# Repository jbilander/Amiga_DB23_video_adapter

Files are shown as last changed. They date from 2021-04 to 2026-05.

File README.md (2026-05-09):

# Amiga DB23 Video Adapter

## Overview

The Amiga DB23 Video Adapter is a small plug-mounted PCB that fits directly onto the Amiga's 
DB23 video port. It is primarily used to build Amiga video cables — either a SCART (RGBS) or 
VGA (RGBHV) cable — while also buffering and filtering the Amiga's analog video signals for 
use with modern displays. Optionally, it allows switching between true PAL and NTSC clock 
frequencies without rebooting or using software.

***

<a href="images/Amiga_DB23_video_adapter_rev1b_pic15.jpg">
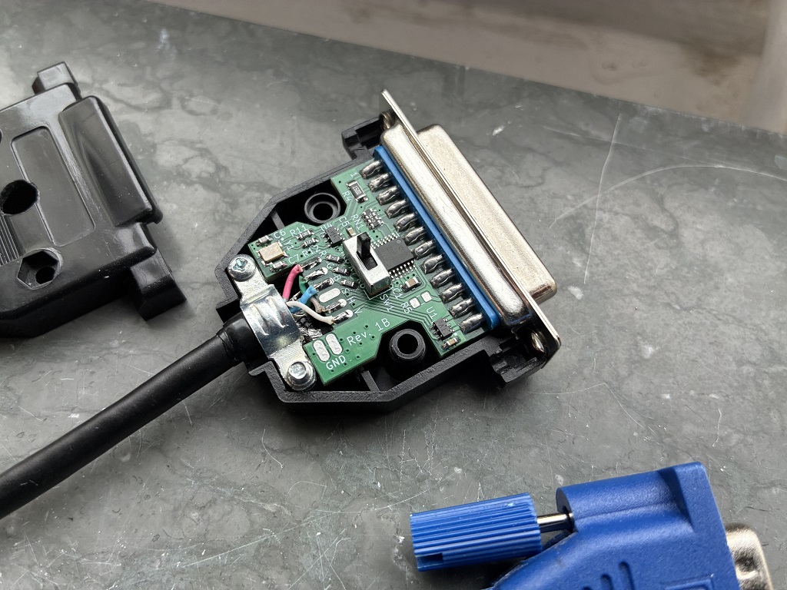
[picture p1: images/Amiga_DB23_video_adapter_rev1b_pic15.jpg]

</a>
<a href="images/Amiga_DB23_video_adapter_rev1b_pic16.jpg">
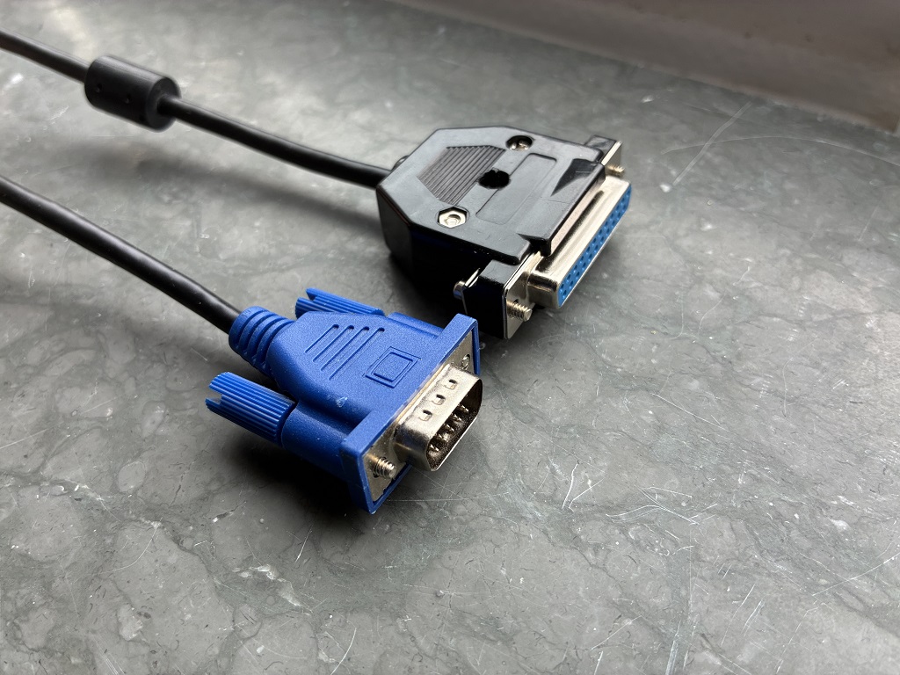
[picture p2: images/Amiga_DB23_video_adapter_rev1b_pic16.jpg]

</a>

***

<a href="images/Amiga_DB23_video_adapter_rev1b_pic1.png">
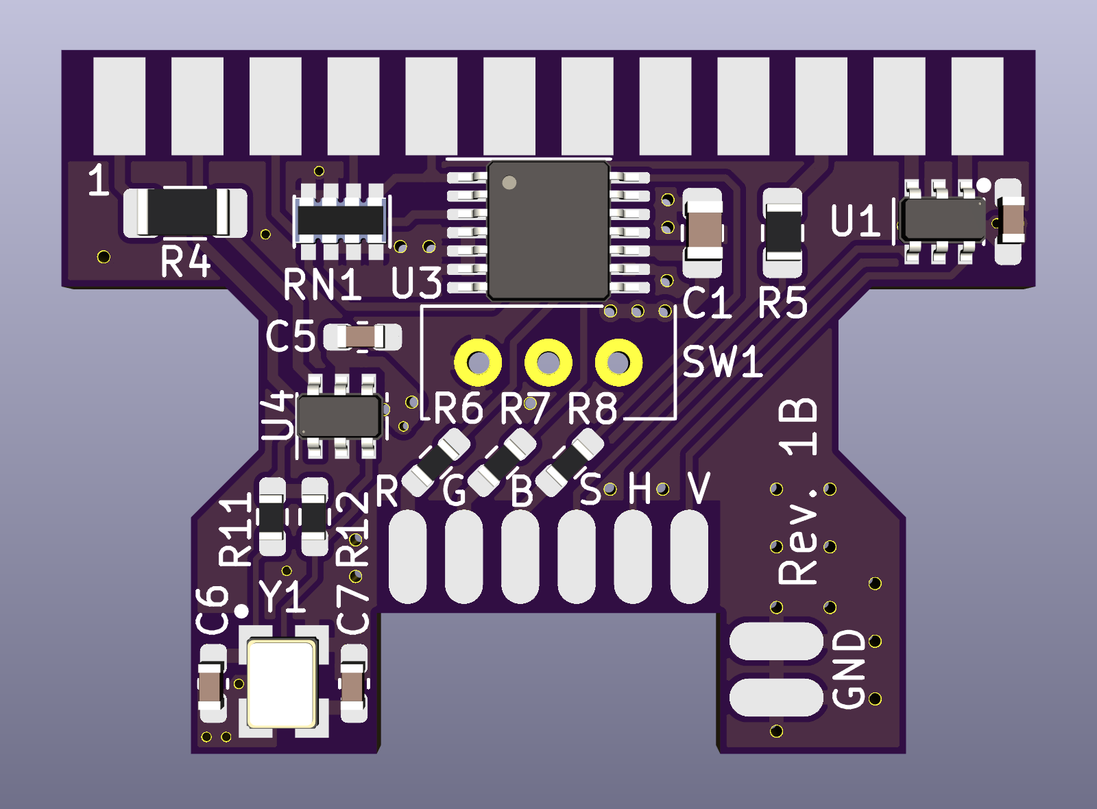
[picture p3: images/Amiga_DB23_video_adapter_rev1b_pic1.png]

</a>
<a href="images/Amiga_DB23_video_adapter_rev1b_pic2.png">
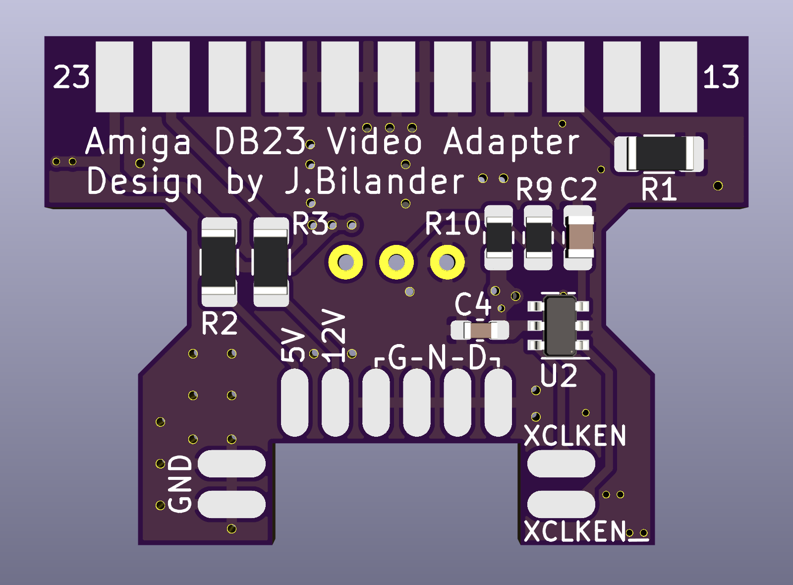
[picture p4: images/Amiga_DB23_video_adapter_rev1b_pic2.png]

</a>
<br />
<a href="images/Amiga_DB23_video_adapter_rev1b_pic3.png">
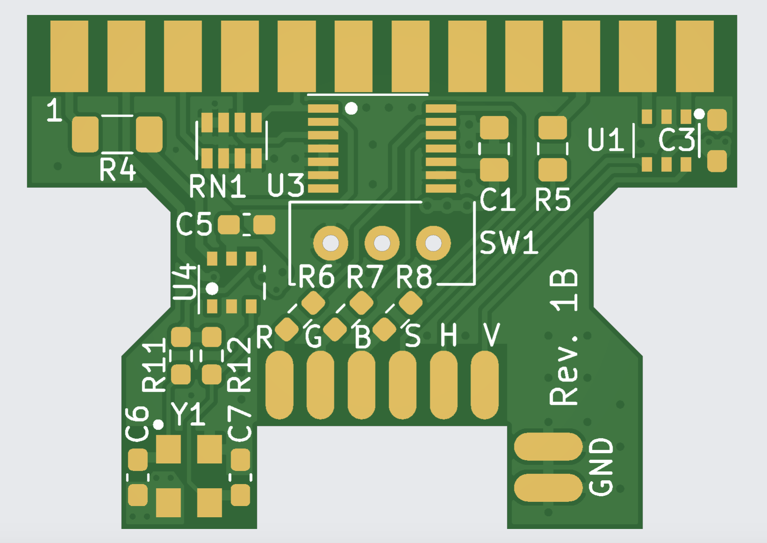
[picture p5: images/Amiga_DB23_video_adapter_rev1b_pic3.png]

</a>
<a href="images/Amiga_DB23_video_adapter_rev1b_pic4.png">
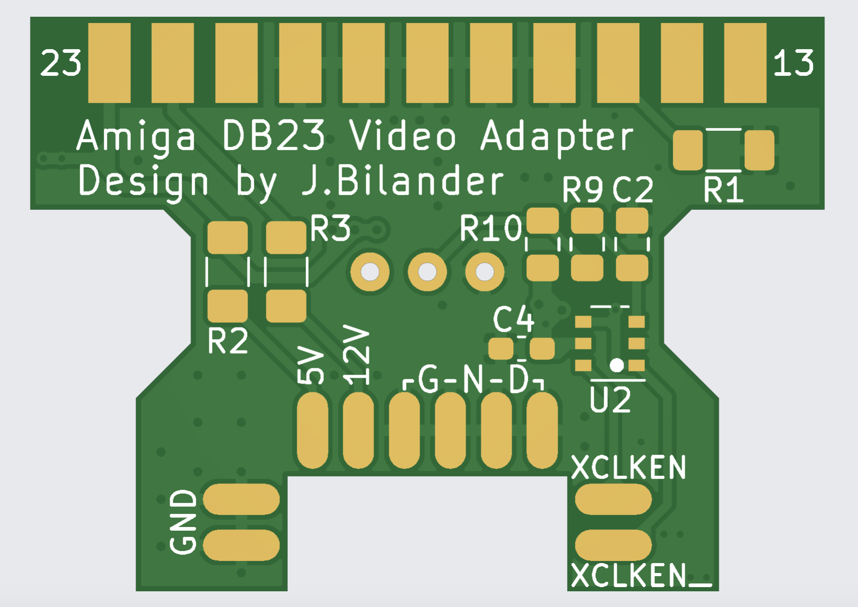
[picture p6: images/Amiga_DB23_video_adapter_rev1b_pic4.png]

</a>

***

### Video Signal Conditioning (Rev 1B)

- **HSync and VSync** are passed through a dual non-inverting Schmitt-trigger buffer (U1) to 
  reduce jitter and noise on the sync lines.
- **RGB signals** are routed through a THS7374 4-channel video amplifier (U3) with its 
  low-pass filter enabled. This effectively removes the horizontal banding and "jailbar" 
  interference patterns commonly seen when connecting an Amiga's 15 kHz signal to LCD displays.
  > ⚠️ A 15 kHz-capable display is required. See [15khz.wikidot.com](http://15khz.wikidot.com/) 
  > for compatible monitors.

### PAL/NTSC Clock Switching (Optional)

When a crystal oscillator (Y1) is populated, the adapter can supply an external pixel clock 
to the Amiga's Agnus/Alice chip, allowing the machine to be switched between PAL and NTSC 
video modes. The slide switch (SW1) enables or disables the `/XCLKEN` signal — when asserted, 
this tells Agnus/Alice to use the external clock from the adapter instead of the onboard 
motherboard oscillator.

The switch itself is hardware-debounced using a resistor-capacitor (RC) circuit combined with 
the hysteresis of a dual-inverting Schmitt-trigger IC (U2), ensuring clean, glitch-free 
switching.

Two solder pads (`XCLKEN` and `/XCLKEN`) are provided on the PCB. An optional jumper wire 
can be soldered from one of these pads back to pin 41 of a switchable Agnus chip 
(or JP4 on the A500 Rev. 6A board), so that the switch on the adapter controls both the 
external clock enable and the Agnus clock selection simultaneously.

> ⚠️ **Before attempting this mod**, verify that your Agnus revision supports hardware 
> PAL/NTSC switching, and confirm that JP4 is not already bridged to GND. 
> All ECS Agnus chips can be switched in **software** if the hardware pin is not available — 
> use the Early Startup Menu (hold both mouse buttons at reset) on KS 3.0+, or a tool 
> such as [Degrader](https://aminet.net/package/util/boot/Degrader).

#### Choosing the correct crystal and solder pad

Install a crystal **opposite** to the one already on your Amiga's motherboard:

| Motherboard oscillator | Install crystal | Solder jumper wire to pad |
|---|---|---|
| PAL (28.37516 MHz) | NTSC (28.63636 MHz) | `XCLKEN` |
| NTSC (28.63636 MHz) | PAL (28.37516 MHz)  | `/XCLKEN` |

> The jumper wire is entirely optional. Without it you can still enable/disable the external 
> clock via SW1, and switch the Agnus video mode independently through software or the 
> Early Startup Menu.

---

## Why use this adapter with XCLK?

You don't have to — but being able to switch between true native PAL and true native NTSC on 
the same machine is a very compelling feature. It gives you:

- ✅ Correct **aspect ratio** for game graphics designed for a specific video standard
- ✅ Correct **sound playback speed** (PAL/NTSC run at different clock rates)
- ✅ Correct **gameplay speed** and smooth scrolling in both PAL 50 Hz and NTSC 60 Hz

For example, compare the screenshots below from *Defender of the Crown*, with its stunning 
artwork by artist **Jim Sachs**. The game was designed for NTSC and looks significantly better 
in NTSC mode (bottom row) — in PAL mode (top row) everything appears vertically squashed.

<br />

**PAL (top) vs NTSC (bottom):**

<a href="images/pal_vs_ntsc_pic1.jpg">
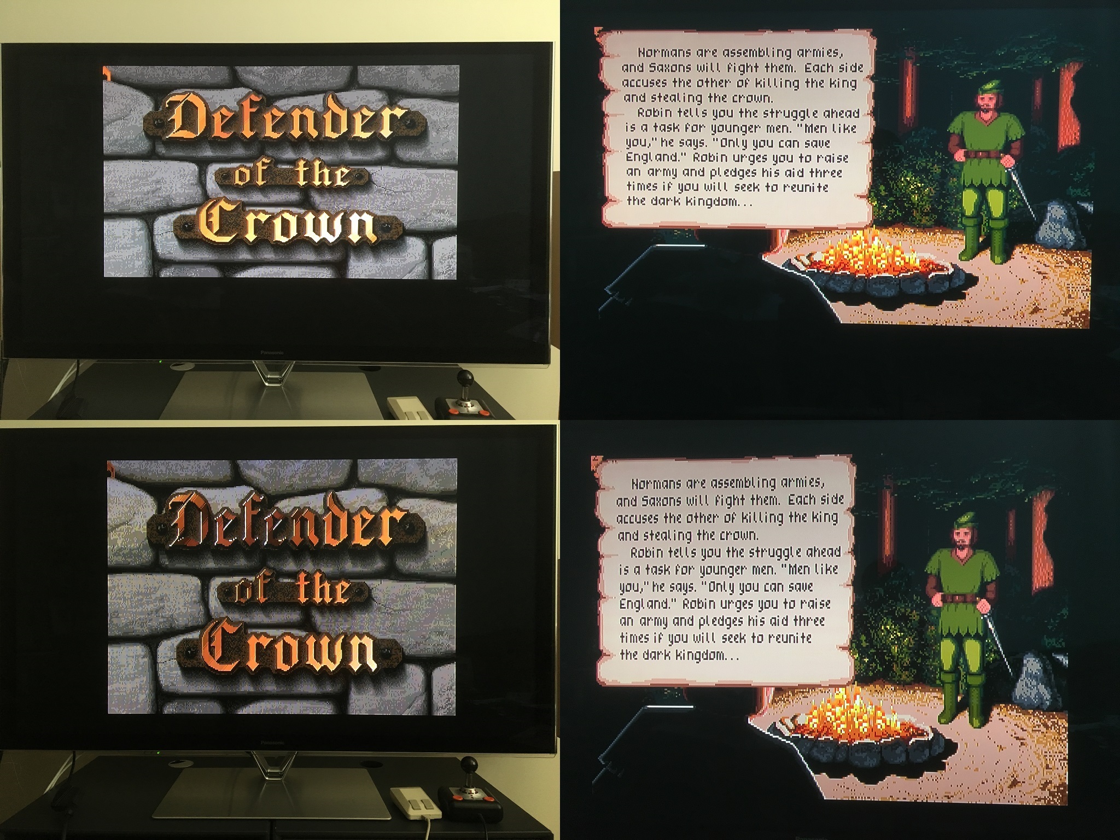
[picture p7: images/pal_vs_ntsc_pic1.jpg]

</a>
<a href="images/pal_vs_ntsc_pic2.jpg">
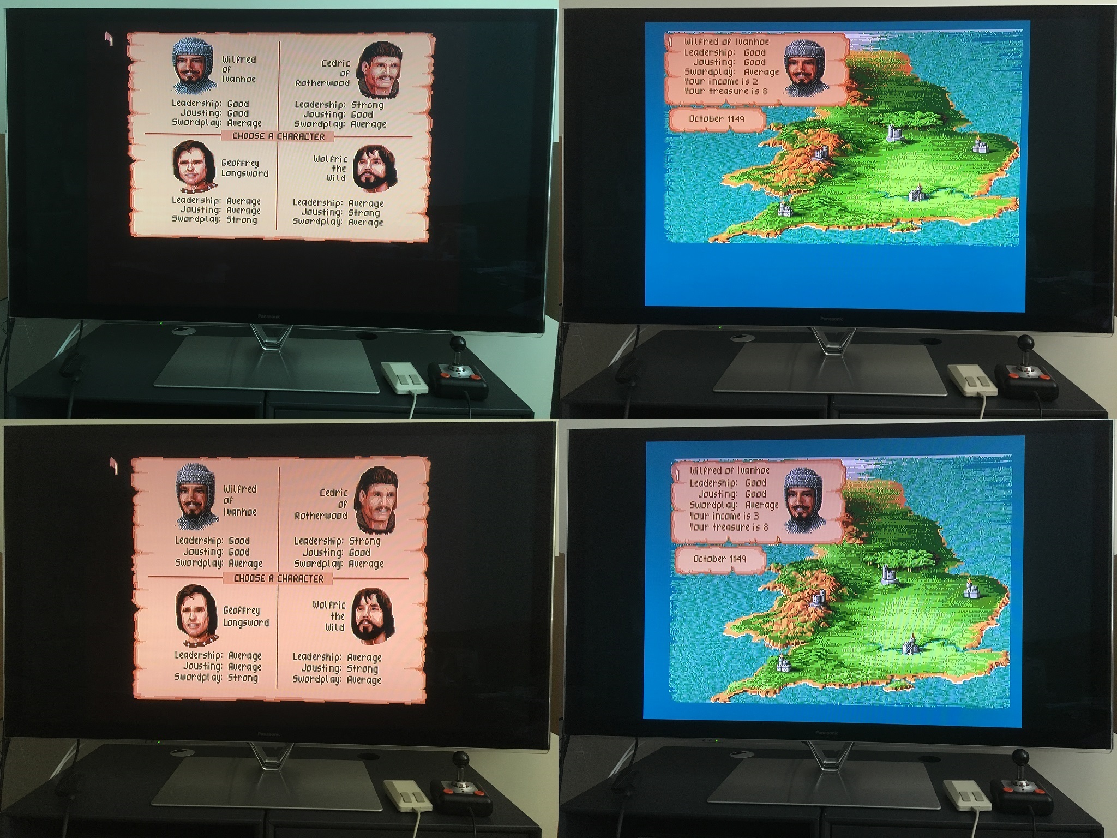
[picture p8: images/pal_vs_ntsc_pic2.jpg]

</a>

***

## Usage Scenarios

### 1 — Amiga DB23 to SCART (RGBS)
Build a cable carrying RGB + Composite Sync (CSync) to a SCART-equipped display.  
U1 and C3 are **not required** in this configuration.  
Y1 can optionally be populated for PAL/NTSC switching as described above.

### 2 — Amiga DB23 to VGA (RGBHV)
Build a cable carrying RGB + separate HSync/VSync to a VGA monitor.  
Requires a [15 kHz-compatible monitor](http://15khz.wikidot.com/).  
U1 and C3 **are required** in this configuration.  
Y1 can optionally be populated for PAL/NTSC switching as described above.

### 3 — Plug only, no cable (clock switching only)
Populate Y1 and the XCLK circuitry, but attach no output cable. Useful if you are already 
using an RGBtoHDMI or similar device for display output but want to retain hardware 
PAL/NTSC switching via the adapter's switch.

***

## Bill of Materials (Rev 1B and 1C)

**J1, U3 and RN1 are required for both SCART and VGA builds.**

| Reference | Qty | Value | Description | Package | Mouser / Notes |
|---|-----|---|---|---|---|
| J1 | 1 | DB23 Female | DB-23 female connector (Amiga video port) | DB-23 | [Aliexpress DB23 Female](https://www.aliexpress.com/item/1005004634222021.html) |
| U1 | 1 | 74HCT2G17 | Dual non-inverting Schmitt-trigger buffer — **VGA only** | TSOP-6 | [771-HCT2G17GV125](https://www.mouser.com/ProductDetail/771-HCT2G17GV125) |
| U2 | 1 | 74HCT2G14 | Dual inverting Schmitt-trigger buffer (SW1 debounce) — **XCLK optional** | TSOP-6 | [771-HCT2G14GV125](https://www.mouser.com/ProductDetail/771-HCT2G14GV125) |
| U3 | 1 | THS7374IPWR | 4-channel video amplifier with low-pass filter | TSSOP-14 | [595-THS7374IPWR](https://www.mouser.com/ProductDetail/595-THS7374IPWR) |
| U4 | 1 | 74LVC1GX04 | Crystal clock buffer — **XCLK optional** | TSOP-6 | [771-LVC1GX04GV125](https://www.mouser.com/ProductDetail/771-LVC1GX04GV125) |
| Y1 | 1 | 28.37516 MHz (PAL) or 28.63636 MHz (NTSC) | Crystal oscillator, CL=16pF — **XCLK optional** | 3.2 x 2.5 mm | e.g. ABM8-28.375MHZ-B2-T (PAL) or ECS-286.3-18-33-JEM-TR (NTSC) |
| RN1 | 1 | 75Ω | Resistor network, 4× 75Ω isolated (CAT16-75R0F4LF) | 1206 | [CAT16-75R0F4LF](https://www.mouser.com/ProductDetail/652-CAT16-75R0F4LF) |
| SW1 | 1 | SW_SPDT | Slide switch, enables/disables `/XCLKEN` (external clock to Agnus/Alice). Recommended: SS12D00 3-pin 1P2T, pin pitch 2.5 mm, handle length 5 mm — **XCLK optional** | | e.g. [AliExpress SS12D00](https://www.aliexpress.com/item/1005008330569768.html) |
| R1 | 1 | 100Ω | **Optional** — CCK clock termination. Populate only if experiencing clock interference noise. See [vidmod fix](http://www.l8r.net/technical/wblock/a4000hard/vidmod.html) | 1206 | |
| R2 | 1 | 75Ω | RGB mode autoselect — **SCART only** (drives SCART pin 16 high for RGB mode) | 1206 | |
| R3 | 1 | 1kΩ | AV mode autoselect — **SCART only** (drives SCART pin 8 high at 9.5–12V so TV automatically switches to SCART input) | 1206 | |
| R4 | 1 | 150Ω | Damping resistor XCLK-line — **XCLK optional** | 1206 | |
| R5 | 1 | 330Ω | CSync resistor — **SCART only** | 0805 | |
| R6, R7, R8 | 3 | 75Ω | Video termination resistor | 0603 | |
| R9, R10 | 2 | 10kΩ | Resistor (SW1 RC debounce) — **XCLK optional** | 0805 | |
| R11 | 1 | 1kΩ | Resistor — **XCLK optional** | 0603 | |
| R12 | 1 | 2.2MΩ | Resistor — **XCLK optional** | 0603 | |
| C1, C2 | 2 | 100nF | Decoupling capacitor | 0805 | (C2 is for SW1 RC debounce)|
| C3 | 1 | 100nF | Decoupling capacitor — **VGA only** | 0603 | |
| C4, C5 | 2 | 100nF | Decoupling capacitor — **XCLK optional** | 0603 | |
| C6, C7 | 2 | 32pF | Crystal load capacitor (06031A320FAT2A) — **XCLK optional** | 0603 | [581-06031A320FAT2A](https://www.mouser.com/ProductDetail/581-06031A320FAT2A) |

### Partial BOM by build type

| Component | Mandatory (both) | SCART only | VGA only | XCLK optional |
|---|:---:|:---:|:---:|:---:|
| J1, U3, RN1 | ✅ | | | |
| C1, R6, R7, R8 | ✅ | | | |
| R2, R3, R5 | | ✅ | | |
| U1, C3 | | | ✅ | |
| U2, U4, Y1, SW1 | | | | ✅ |
| C2, C4, C5, C6, C7 | | | | ✅ |
| R4, R9, R10, R11, R12 | | | | ✅ |
| R1 | optional | | | |

### SCART cable wiring reference

| Signal | Resistor | Value | SCART pin | Notes |
|---|---|---|---|---|
| CSync  | R5 | 330Ω | Pin 20 | Composite sync / composite video in, 1V incl. sync |
| +5V | R2 | 75Ω  | Pin 16 | RGB select: High (1–3V) = RGB mode, Low (0–0.4V) = Composite |
| +12V | R3 | 1kΩ  | Pin 8  | AV autoswitch: High (9.5–12V) = AV mode, Low (0–2V) = TV mode |

### VGA cable reference

U1 (74HCT2G17) buffers HSync and VSync. Datasheet: [74HC/HCT2G17](https://assets.nexperia.com/documents/data-sheet/74HC_HCT2G17.pdf)

---

## How to build Rev 1B

The following step-by-step guide documents a VGA (RGBHV) cable build using a cheap 
thin VGA cable as the source, which works very well since these cables already contain 
individually shielded wires inside.

### Step 1 — Prepare the DB23 connector

<a href="images/Amiga_DB23_video_adapter_rev1b_pic5.jpg">
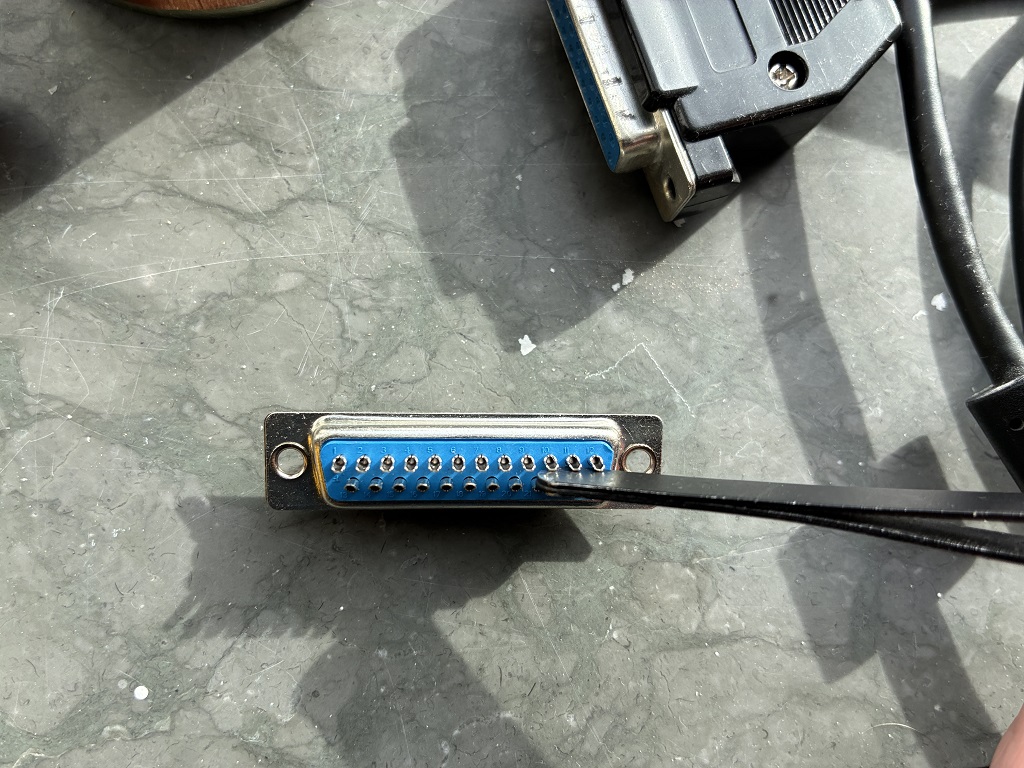
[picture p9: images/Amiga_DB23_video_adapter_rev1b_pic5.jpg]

</a>

Start by gently prying the solder lug pins outward slightly on the DB23 connector so 
that they can wrap around the standard 1.6 mm PCB thickness. The back of a pair of 
tweezers works well for this — just enough to open them up without bending them too far.

### Step 2 — Fit the PCB into the connector

<a href="images/Amiga_DB23_video_adapter_rev1b_pic6.jpg">
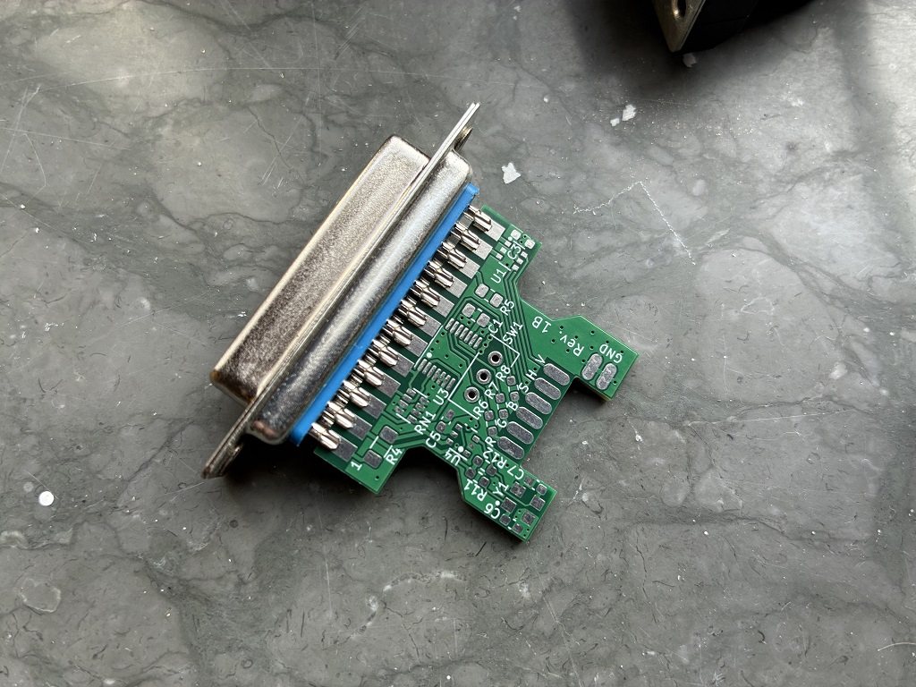
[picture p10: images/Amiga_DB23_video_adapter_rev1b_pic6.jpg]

</a>

Carefully sandwich the PCB between the solder cups of the connector, making sure the 
alignment is correct. The fit is very tight — press the PCB in by hand as far as it 
will go. At this stage there will still be a small gap visible between the blue plastic 
back of the connector and the PCB edge; this is expected.

### Step 3 — Press the PCB fully home in a vise

<a href="images/Amiga_DB23_video_adapter_rev1b_pic7.jpg">
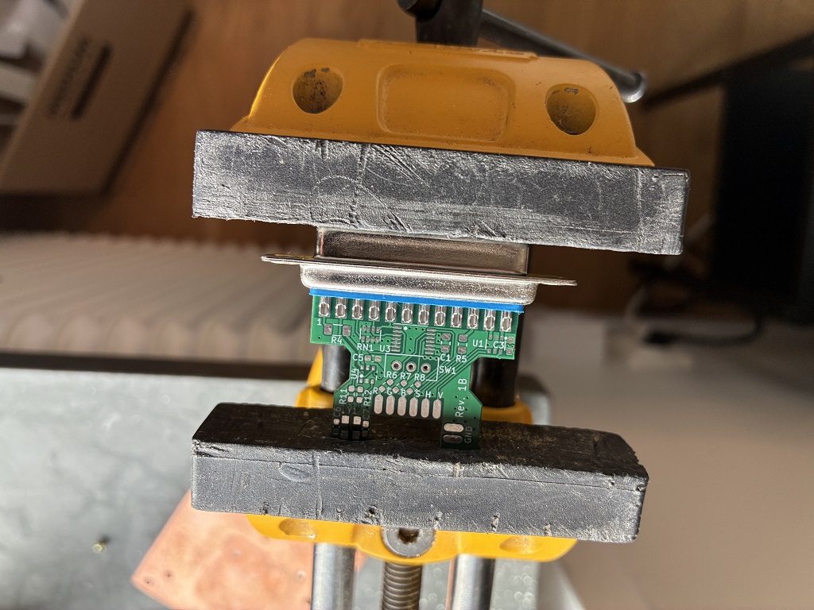
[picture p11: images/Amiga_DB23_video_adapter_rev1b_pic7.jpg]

</a>

Place the PCB and connector assembly into a bench vise as shown, then slowly tighten 
the vise to press the PCB all the way flush against the plastic back of the connector.

### Step 4 — Test fit in the plastic shell

<a href="images/Amiga_DB23_video_adapter_rev1b_pic8.jpg">
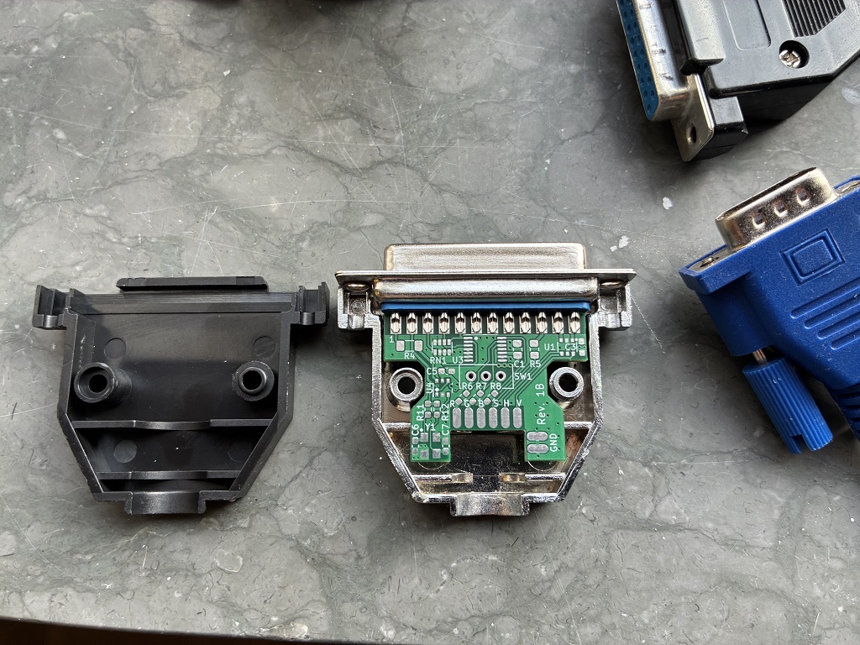
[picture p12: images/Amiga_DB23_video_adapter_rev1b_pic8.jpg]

</a>
<a href="images/Amiga_DB23_video_adapter_rev1b_pic9.jpg">
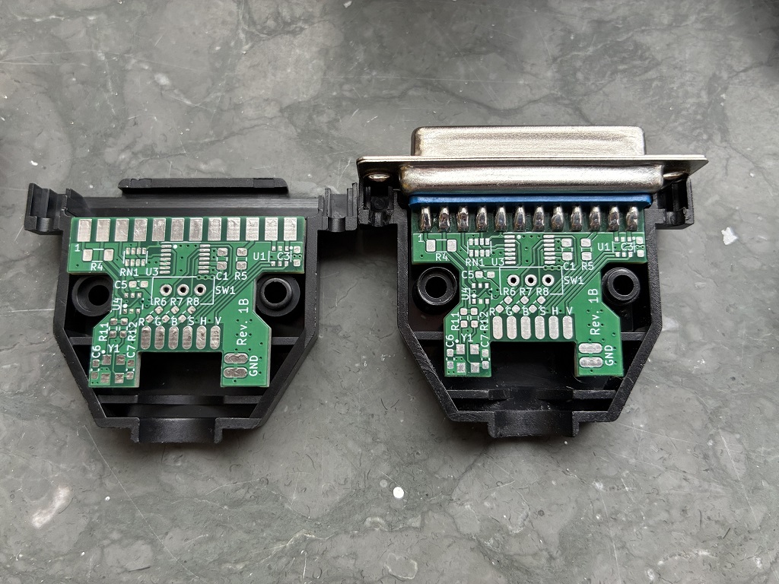
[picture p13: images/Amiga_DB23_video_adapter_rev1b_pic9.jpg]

</a>

Test that the assembly fits inside the plastic shell and clears the screw terminal posts.

> **Note on shell compatibility:**
> - **Older DB23 shells** have approximately 21.5 mm clearance between the screw terminal 
>   posts — Rev 1B (20.6 mm wide) fits these without any modification.
> - **Newer shells** (available from [AliExpress](https://www.aliexpress.com/item/1005004634222021.html)) 
>   have only 20 mm spacing, which means Rev 1B overlaps the posts by about 0.6 mm and 
>   the two shell halves will not close without a slight carve or filing of the plastic posts.
> - **Rev 1C** has been narrowed to 19.8 mm and fits the new shells without any modification. 
>   Rev 1B and Rev 1C are otherwise electrically identical — the BOM and schematic are the same.

In pic9, the right side shows a fully soldered connector test-fitted in an older shell 
where it clears the posts cleanly. On the left you can see a bare PCB test-fitted in the 
newer style shell, where the slight overlap on the posts is visible.

Once you have confirmed the fit, solder all the connector solder cups on both sides of 
the PCB and connector.

### Step 5 — Solder the SMD components

With the connector soldered, proceed to populate and solder the SMD components on the 
PCB. If you are fitting the optional crystal oscillator (Y1) for XCLK switching, it is 
recommended to reflow it first with a hot air rework station before populating nearby 
smaller components that could otherwise be displaced by the airflow. All other SMD 
components can be soldered with a regular soldering iron.

Leave the through-hole slide switch (SW1) until last — it is easier to solder everything 
else first without the switch body in the way.

> **Tip on cable shielding:** It is good practice to solder the cable's outer shielding 
> braid to the DB23 connector's metal shell. The Amiga's DB23 shell is connected to GND 
> on the motherboard, so having the shield connected here means GND will make contact 
> first if the cable is ever hot-plugged, protecting the circuitry. A high-powered 
> soldering iron or desoldering gun (such as the ZD-915) with sufficient thermal mass 
> is recommended for this step. Pre-crimping a Dupont male pin onto the bundled shielding 
> wire makes it easier to tin and solder to the shell.

### Step 6 — Modify the shell for the cable strain relief

<a href="images/Amiga_DB23_video_adapter_rev1b_pic10.jpg">
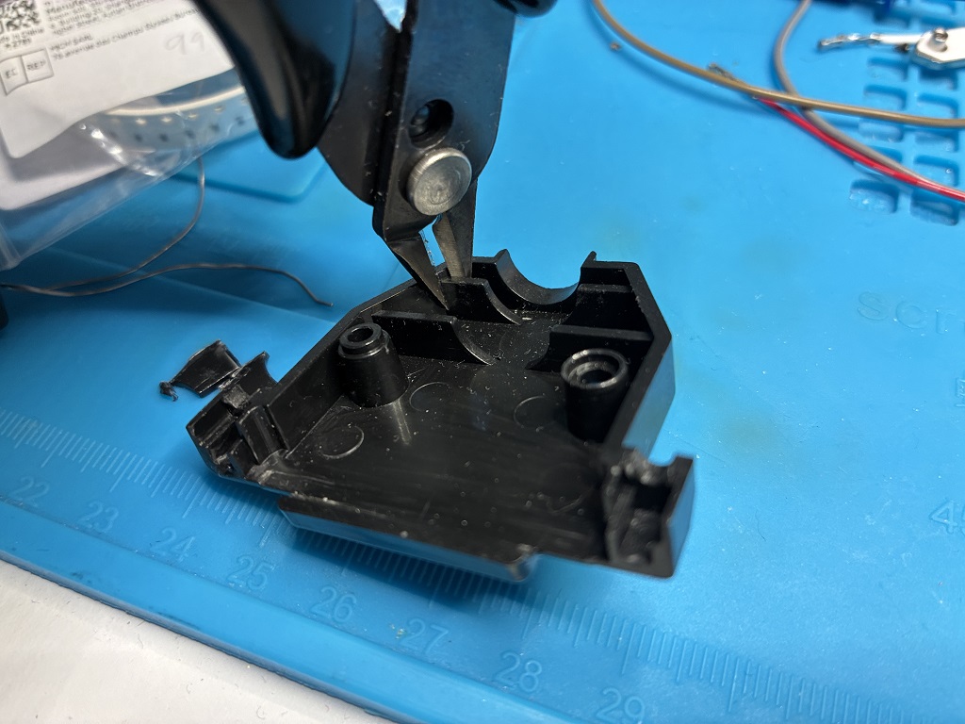
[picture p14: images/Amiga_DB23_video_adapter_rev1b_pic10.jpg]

</a>

To fit the metal cable strain relief inside the shell, the two small inner plastic walls 
nearest the cable exit hole need to be removed — they are the ones that interfere with 
the strain relief clamp. Use a pair of electronics pliers or flush cutters to snip them 
off as close to the side wall and floor of the shell as possible. Be careful to only 
remove the two pieces immediately next to the exit hole, not the similar supports further 
inside that the PCB rests on.

### Step 7 — Modify the strain relief to fit

<a href="images/Amiga_DB23_video_adapter_rev1b_pic11.jpg">
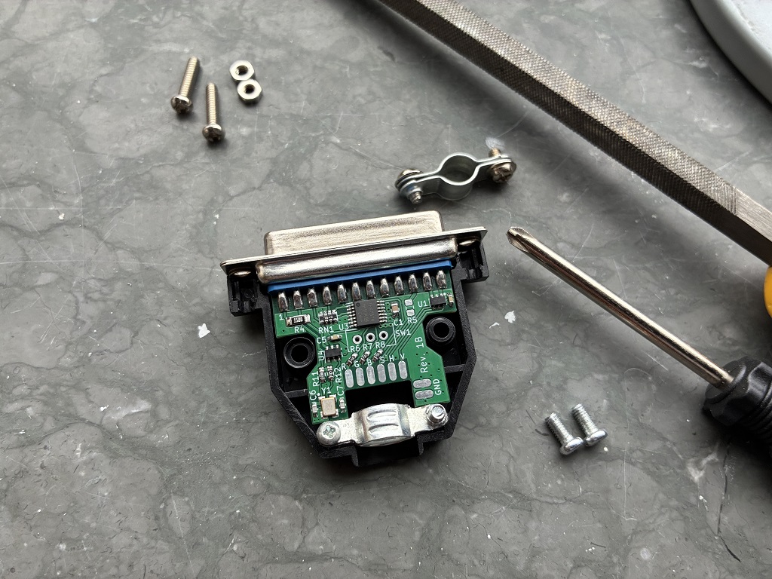
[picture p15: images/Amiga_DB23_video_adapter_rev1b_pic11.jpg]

</a>

The standard metal cable strain relief may need a small amount of filing to fit 
comfortably inside the shell. The standard M3 screws supplied with the strain relief 
may also need to be swapped for M3 screws with a lower-profile head. Once modified, 
the strain relief fits neatly wedged between the back edge of the PCB and the rear 
wall of the shell. Alternatively, a custom strain relief could be 3D printed in plastic 
to avoid the need for any hand filing.

### Step 8 — Drill the switch hole

<a href="images/Amiga_DB23_video_adapter_rev1b_pic12.jpg">
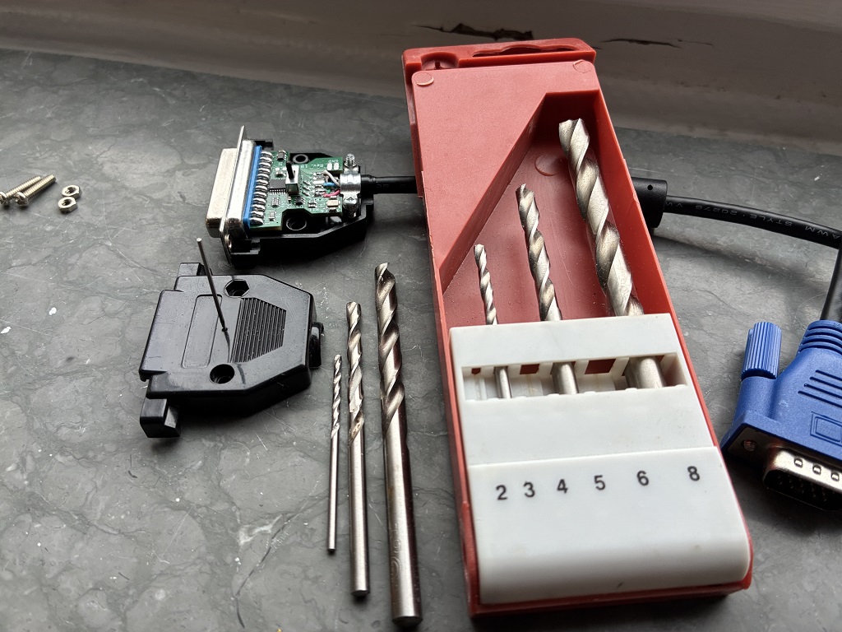
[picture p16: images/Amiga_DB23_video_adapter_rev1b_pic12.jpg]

</a>

One half of the plastic shell needs a hole drilled for the SW1 switch handle to protrude 
through. Mark the centre point with a sharp tweezer or scribe — it sits midway between 
the two screw holes, and midway between the recessed label area and the thumb-grip 
grooves on the shell.

Start with a 1 mm drill bit turned carefully by hand to establish a centred pilot hole, 
then step up through 2 mm, 4 mm, and finally 6 mm using a power drill. A 6 mm diameter 
hole gives the switch handle enough room to travel freely between both positions without 
touching the sides.

### Step 9 — Test fit the switch

<a href="images/Amiga_DB23_video_adapter_rev1b_pic13.jpg">
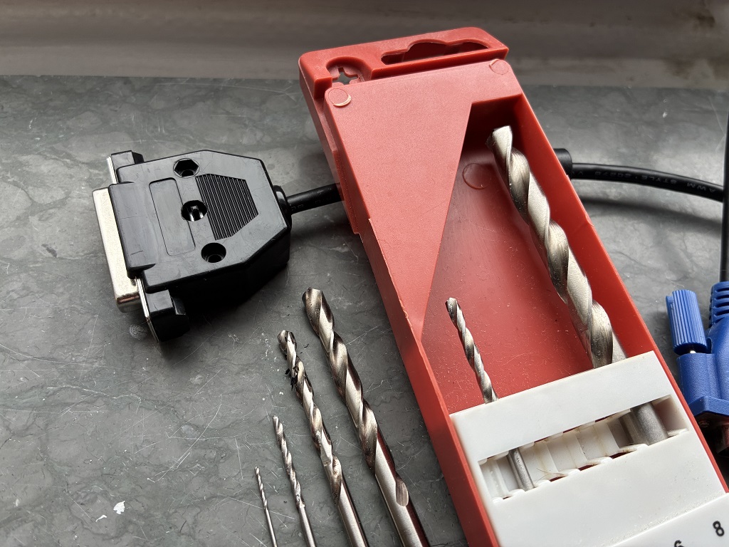
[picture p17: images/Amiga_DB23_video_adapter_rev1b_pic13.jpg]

</a>

Test fit the shell halves and confirm that the switch handle protrudes a few millimetres 
through the hole and can be toggled comfortably between both positions by hand.

### Step 10 — Solder the cable wires

<a href="images/Amiga_DB23_video_adapter_rev1b_pic14.jpg">
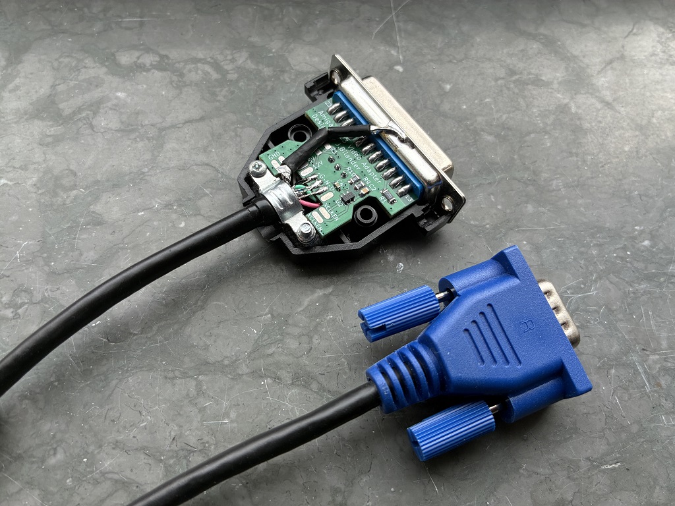
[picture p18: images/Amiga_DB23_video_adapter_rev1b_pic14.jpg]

</a>
<a href="images/Amiga_DB23_video_adapter_rev1b_pic15.jpg">

</a>

Solder the cable wires to the solder pads on the PCB:

- **Underside (pic14):** All GND wires are soldered here. In this VGA build the 5V and 
  12V pads are unused.
- **Front side (pic15):** The analogue Red, Green and Blue signal wires are soldered to 
  their respective pads, along with HSync (grey wire) and VSync (white wire).

### Step 11 — The finished cable

<a href="images/Amiga_DB23_video_adapter_rev1b_pic16.jpg">

</a>

The completed Amiga DB23 to VGA cable. The cable used here is a standard thin VGA cable, 
which despite being inexpensive is an excellent choice as the individual signal wires 
inside are already shielded.

---

## How to build a SCART (RGBS) cable — Rev 1B

The following documents a SCART cable build. This build also includes audio by extending 
wires from a separate RCA cable into the SCART cable, giving you a complete audio/video 
solution in a single plug.

### Step 1 — Solder the top side signal wires

<a href="images/Amiga_DB23_video_adapter_rev1b_pic25.jpg">
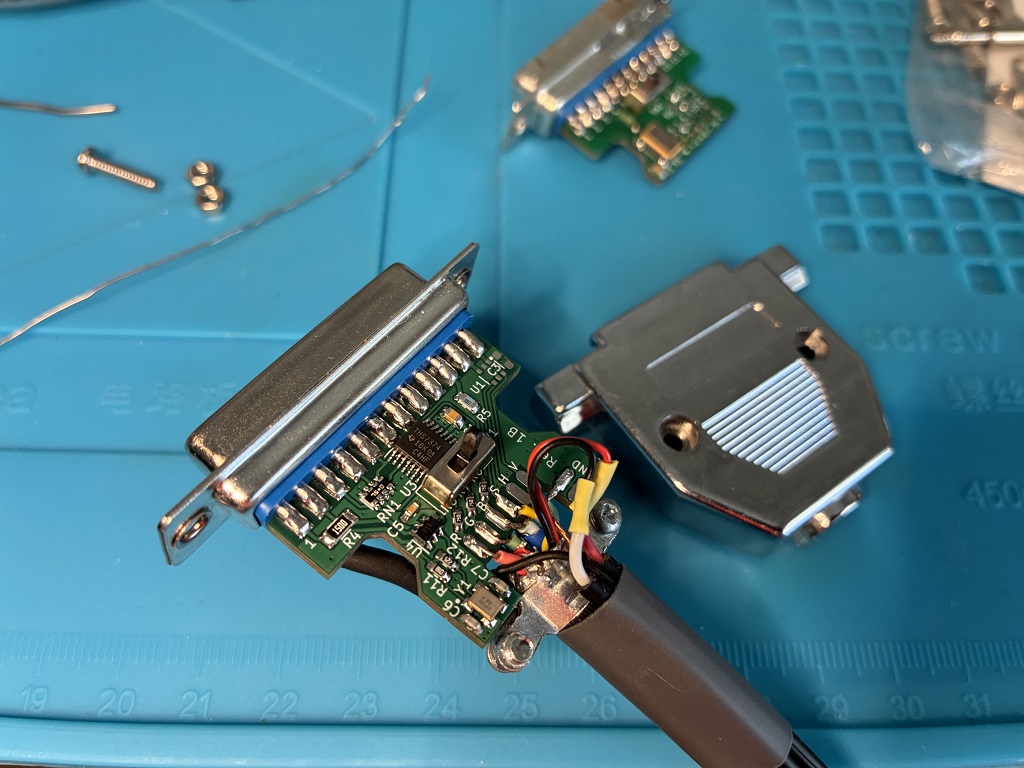
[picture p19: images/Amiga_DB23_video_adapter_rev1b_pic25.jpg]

</a>

The top side of the PCB with all signal wires soldered. The Red, Green and Blue wires 
connect to the R, G and B pads respectively, and the yellow wire carries CSync to the S 
pad. The audio channels are extended from a separate RCA cable — Red (Right channel) and 
black-to-white (Left channel) — running alongside the video wires into the SCART cable. 
The two audio GND return wires are bundled together and soldered to the GND pad on the 
side of the PCB.

### Step 2 — Crimp and sleeve the audio wire extensions

<a href="images/Amiga_DB23_video_adapter_rev1b_pic26.jpg">
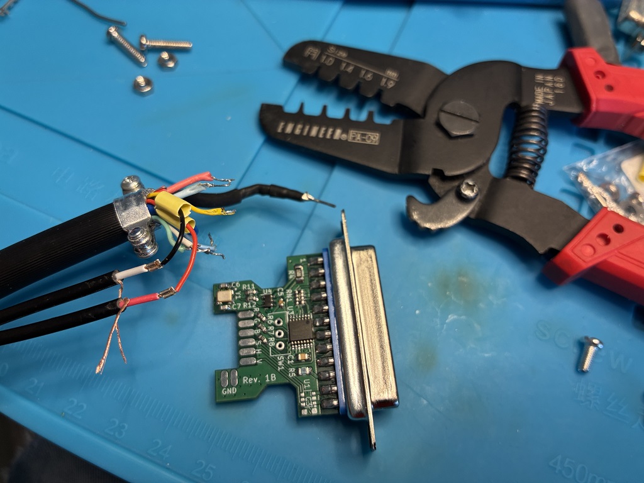
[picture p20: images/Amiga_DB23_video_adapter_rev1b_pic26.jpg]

</a>

The audio wire extensions were first crimped and then soldered for a solid mechanical and 
electrical connection. Heat shrink tubing was applied over each joint and carefully 
shrunk at 150°C using a hot air station, giving a clean and well-insulated result as 
seen in pic25.

### Step 3 — Solder the underside wires

<a href="images/Amiga_DB23_video_adapter_rev1b_pic27.jpg">
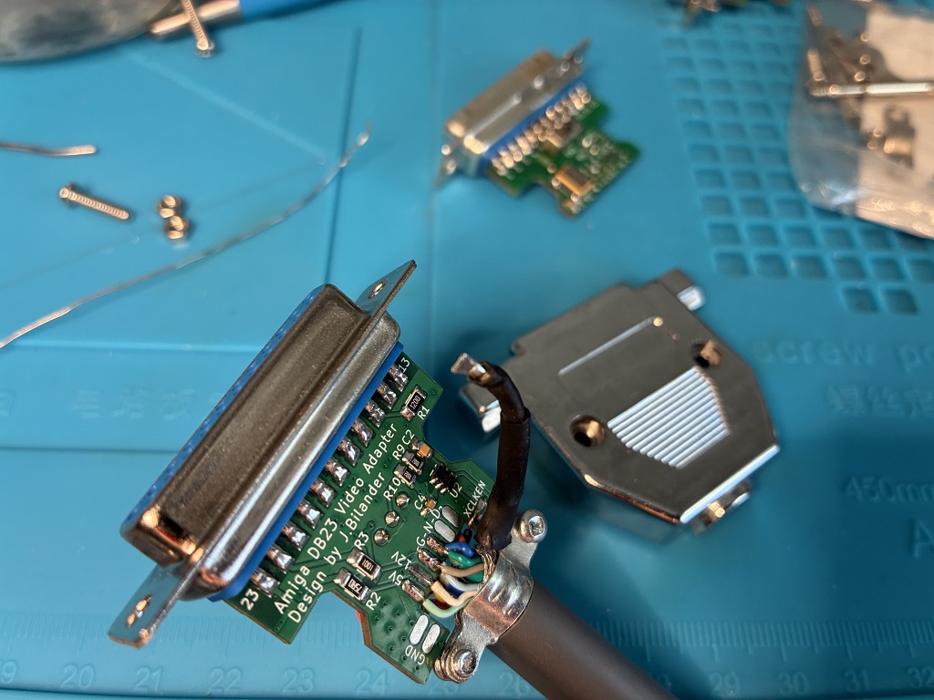
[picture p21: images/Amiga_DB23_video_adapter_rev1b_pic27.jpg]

</a>

The underside of the PCB with everything soldered except the shield ground. Visible here 
are the 5V and 12V wires, the GND wires (main GND plus three RGB return GND wires), and 
the optional fly-lead wire to the `XCLKEN` pad for hardware PAL/NTSC switching via a 
jumper wire to Agnus.

### Step 4 — Solder the cable shielding to the D-Sub metal shell

<a href="images/Amiga_DB23_video_adapter_rev1b_pic28.jpg">
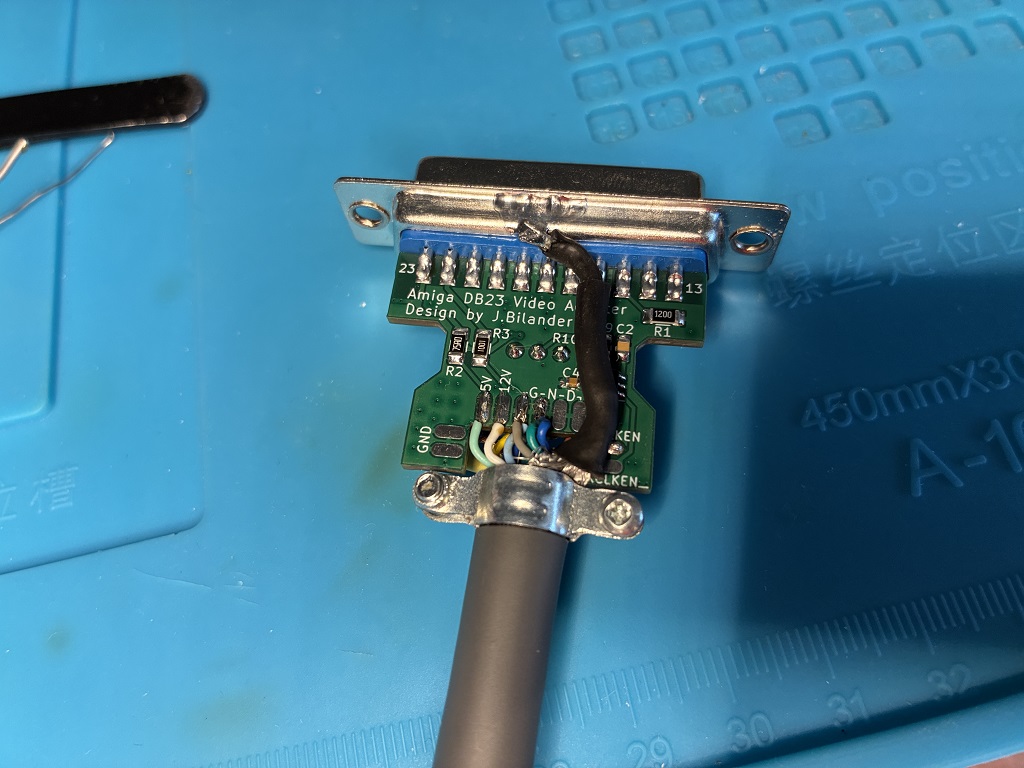
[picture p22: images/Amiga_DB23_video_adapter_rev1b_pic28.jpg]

</a>

The cable's outer shielding braid is soldered directly to the DB23 D-Sub metal shell. 
This grounds the shielding and is particularly important for hot-plugging — with the 
shield connected to the Amiga's motherboard GND via the DB23 shell, GND makes contact 
first when the plug is inserted, protecting the circuitry from damage.

### Step 5 — Fit the cable into the shell with strain relief

<a href="images/Amiga_DB23_video_adapter_rev1b_pic29.jpg">
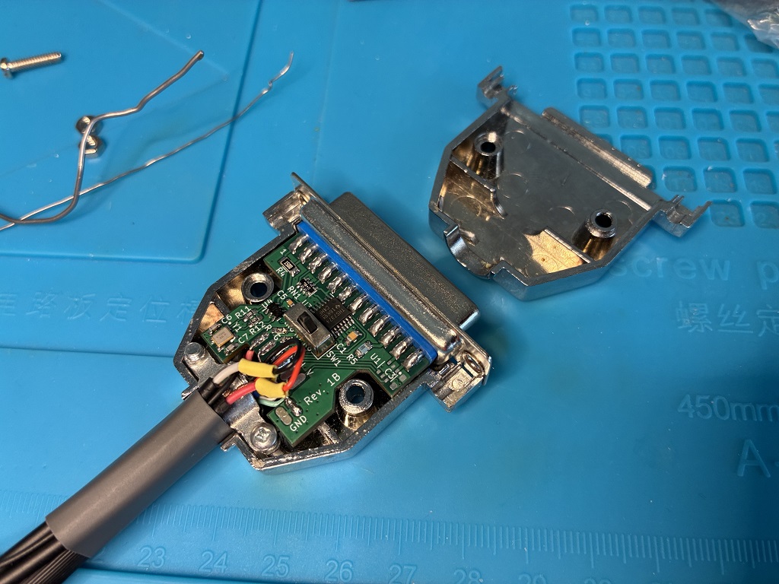
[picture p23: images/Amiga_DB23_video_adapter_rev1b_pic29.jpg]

</a>

The fully built cable assembly fitted inside the DB23 shell with the strain relief in 
place. The strain relief needed filing down to fit comfortably in the somewhat cramped 
interior, as described in the VGA build guide above.

### Step 6 — The completed SCART plug

<a href="images/Amiga_DB23_video_adapter_rev1b_pic30.jpg">
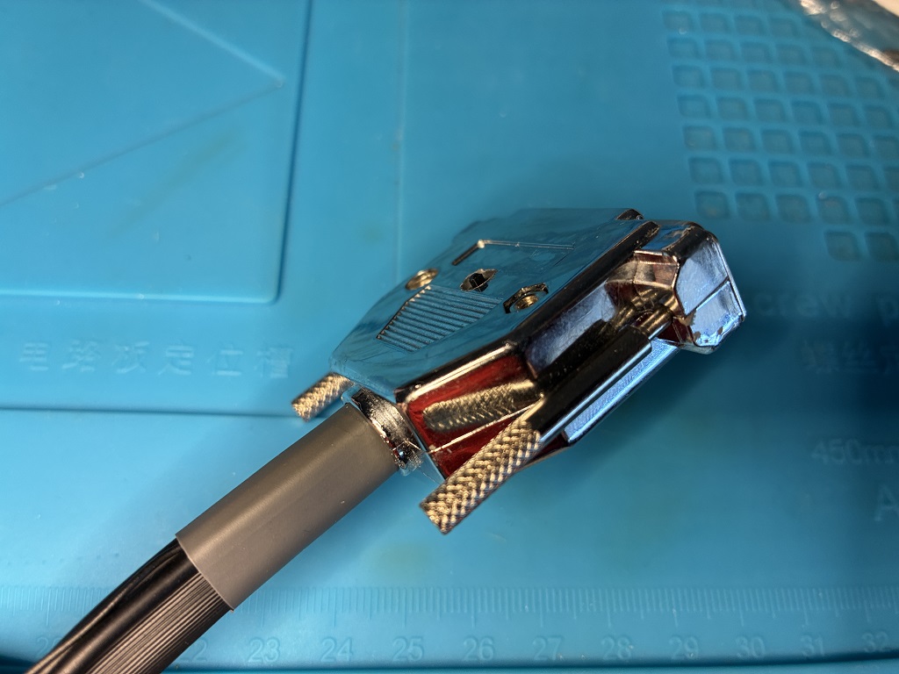
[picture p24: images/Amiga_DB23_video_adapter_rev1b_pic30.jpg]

</a>

The completed plug with the 5 mm hole drilled for the switch handle, which protrudes 
cleanly and travels freely between both positions without obstruction.

### Step 7 — The result: sharp picture quality via SCART

<a href="images/Amiga_DB23_video_adapter_rev1b_pic31.jpg">
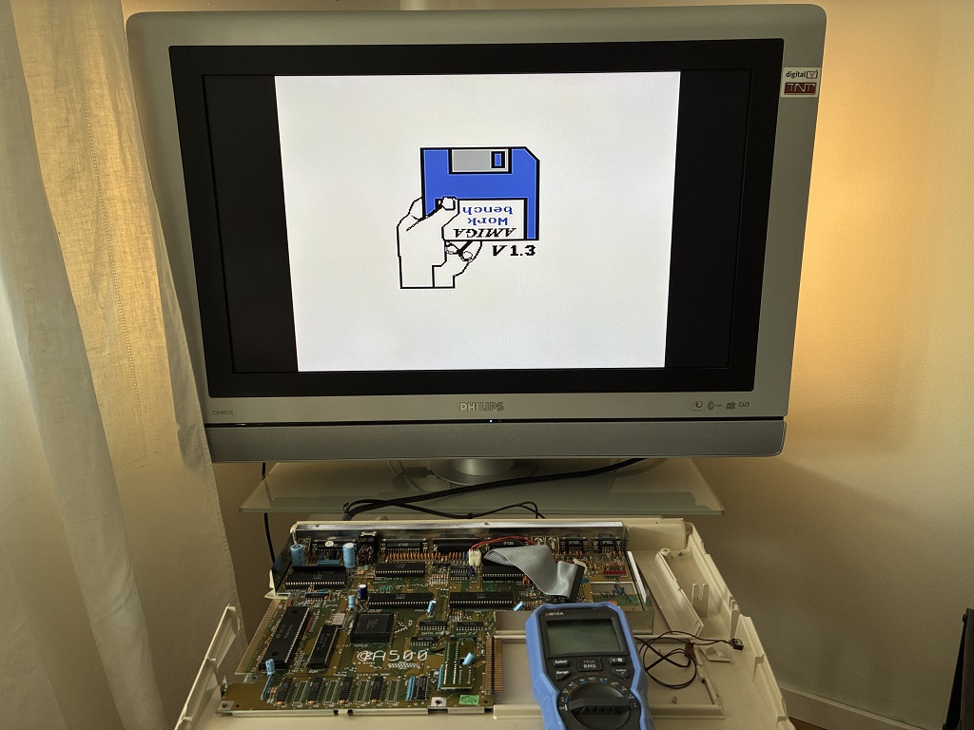
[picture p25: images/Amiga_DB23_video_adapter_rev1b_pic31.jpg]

</a>

The Kickstart 1.3 boot screen displayed via the SCART cable on a TV. The picture quality 
is excellent — sharp, well-saturated RGB with no banding or jailbar artefacts. Almost 
HDMI-like quality from a 15 kHz analog signal.

### Step 8 — The cable connected to the Amiga 500

<a href="images/Amiga_DB23_video_adapter_rev1b_pic32.jpg">
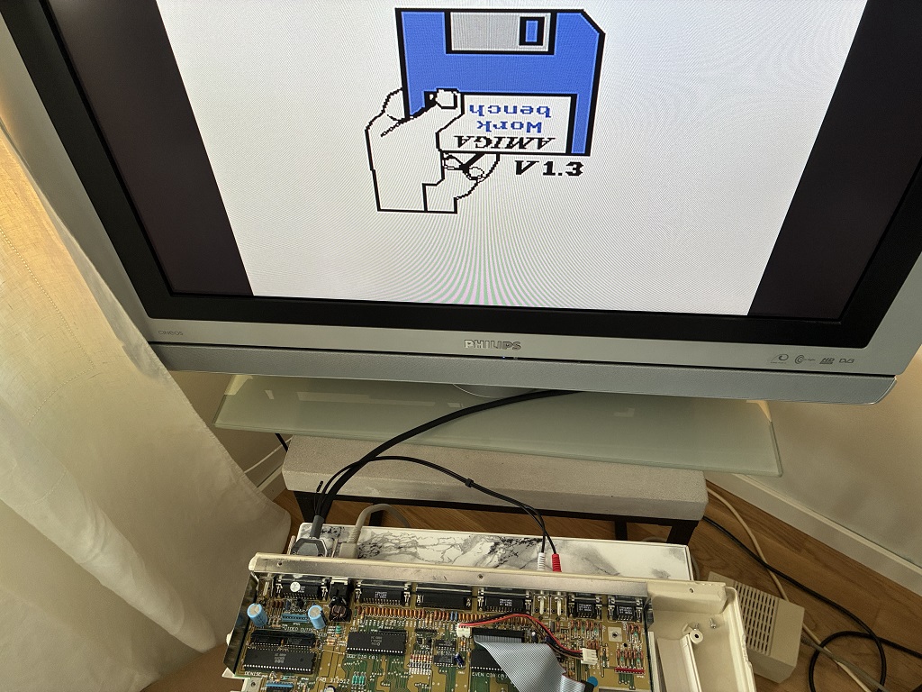
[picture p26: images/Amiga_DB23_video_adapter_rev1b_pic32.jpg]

</a>

A close-up of the completed SCART cable plugged into the Amiga 500, with the separate 
RCA audio cable also connected.

---

## Rev 1B in action

### The cable connected to an Amiga 500+

<a href="images/Amiga_DB23_video_adapter_rev1b_pic17.jpg">
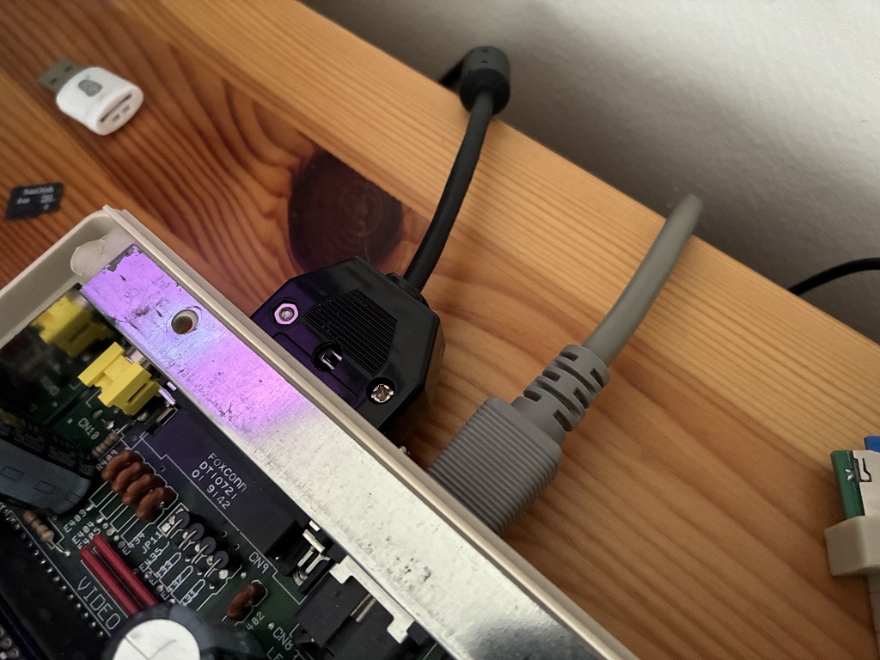
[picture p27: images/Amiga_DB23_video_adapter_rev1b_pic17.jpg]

</a>

The DB23 end of the completed VGA cable plugged into the Amiga 500+. The switch handle 
is clearly visible on the side of the shell and can be toggled by hand to switch between 
PAL and NTSC clock modes.

### XCLK signal verified on the oscilloscope

<a href="images/Amiga_DB23_video_adapter_rev1b_pic19.png">
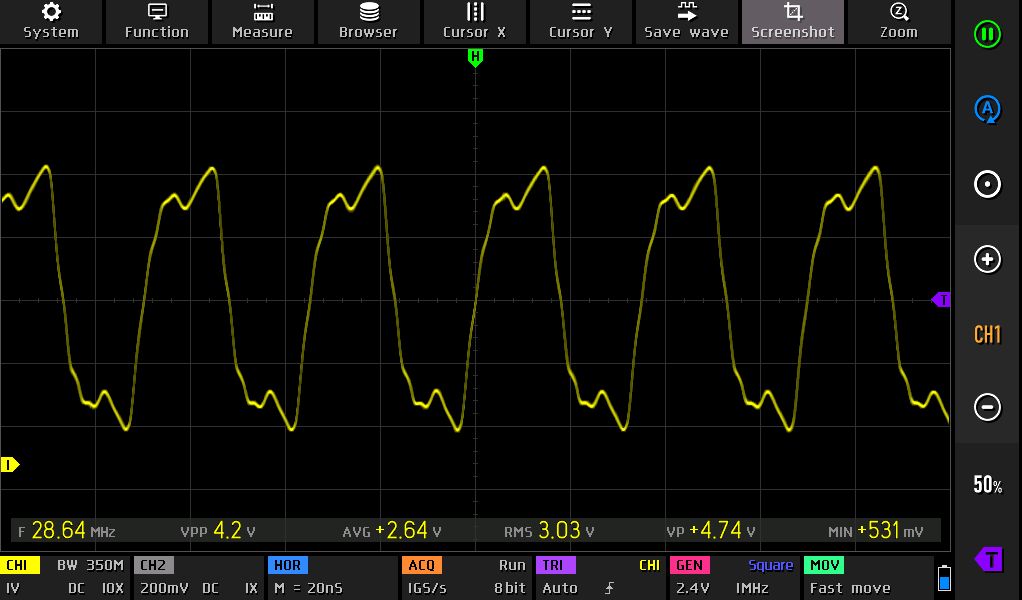
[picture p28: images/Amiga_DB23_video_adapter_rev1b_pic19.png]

</a>

Oscilloscope capture of the XCLK signal measured at pin 1 on the back of the Amiga DB23 
male connector. The adapter produces a clean 28.64 MHz clock signal as expected for NTSC 
operation.

### Working on the BenQ BL912 — PAL and NTSC

The BenQ BL912 is an excellent 15 kHz-capable monitor for use with the Amiga. The monitor 
OSD System → Information screen confirms the signal being received directly from the VGA 
cable via D-Sub input.

<a href="images/Amiga_DB23_video_adapter_rev1b_pic18.jpg">
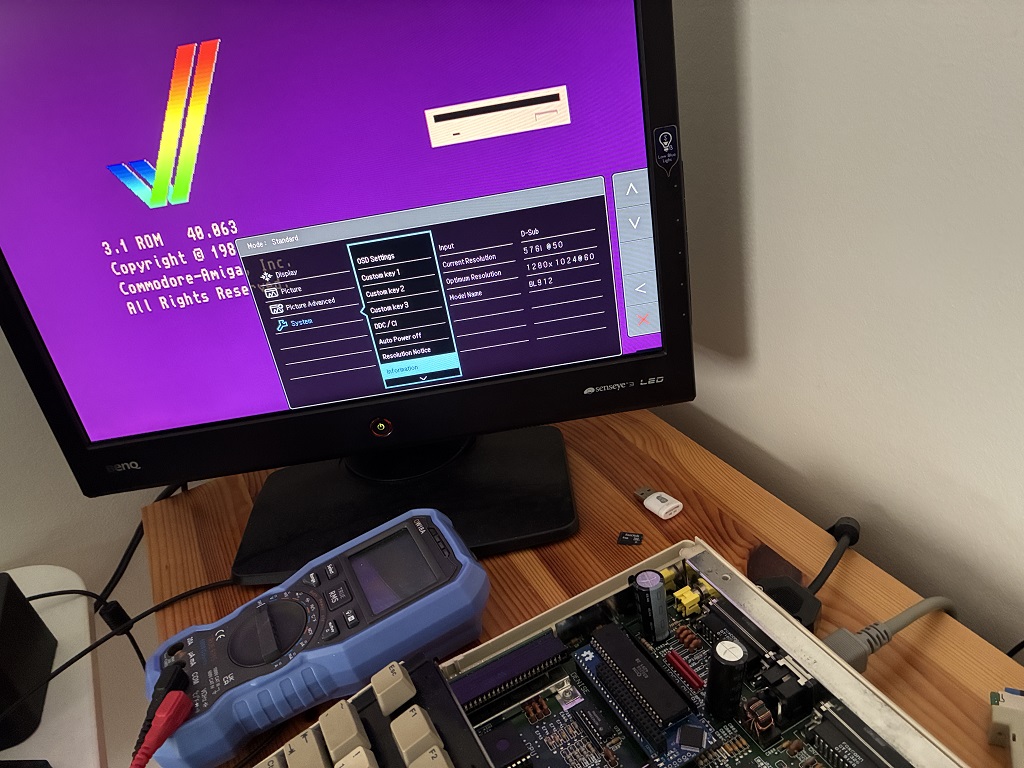
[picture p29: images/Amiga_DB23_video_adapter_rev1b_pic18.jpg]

</a>
<a href="images/Amiga_DB23_video_adapter_rev1b_pic22.jpg">
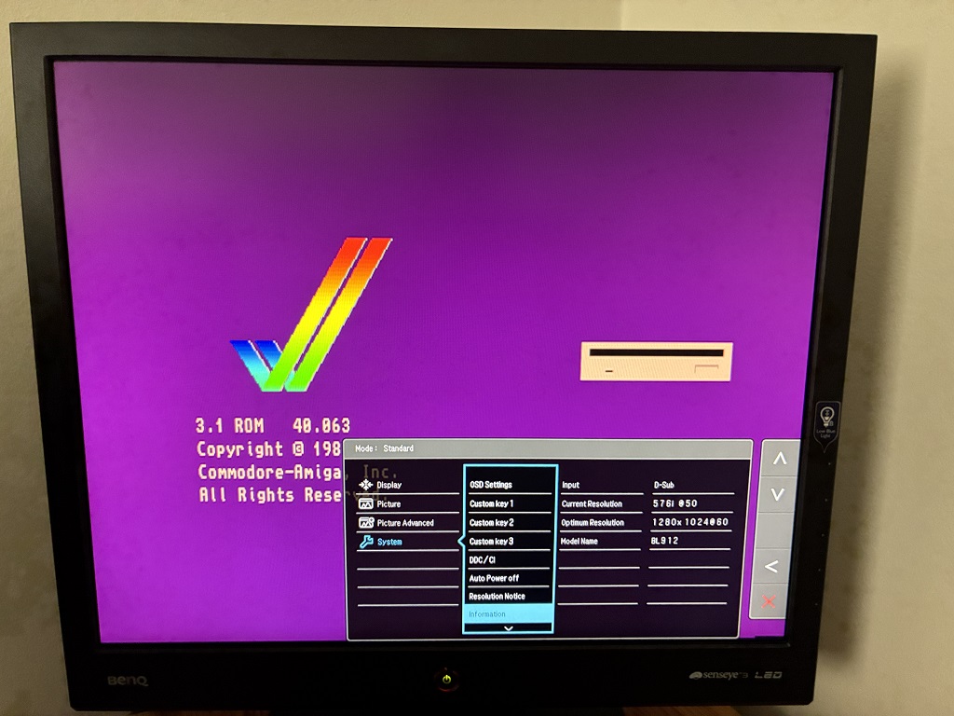
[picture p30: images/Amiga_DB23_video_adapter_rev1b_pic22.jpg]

</a>

**PAL mode** — the monitor information screen shows the Amiga running at 576i @ 50 Hz 
over D-Sub.

<a href="images/Amiga_DB23_video_adapter_rev1b_pic20.jpg">
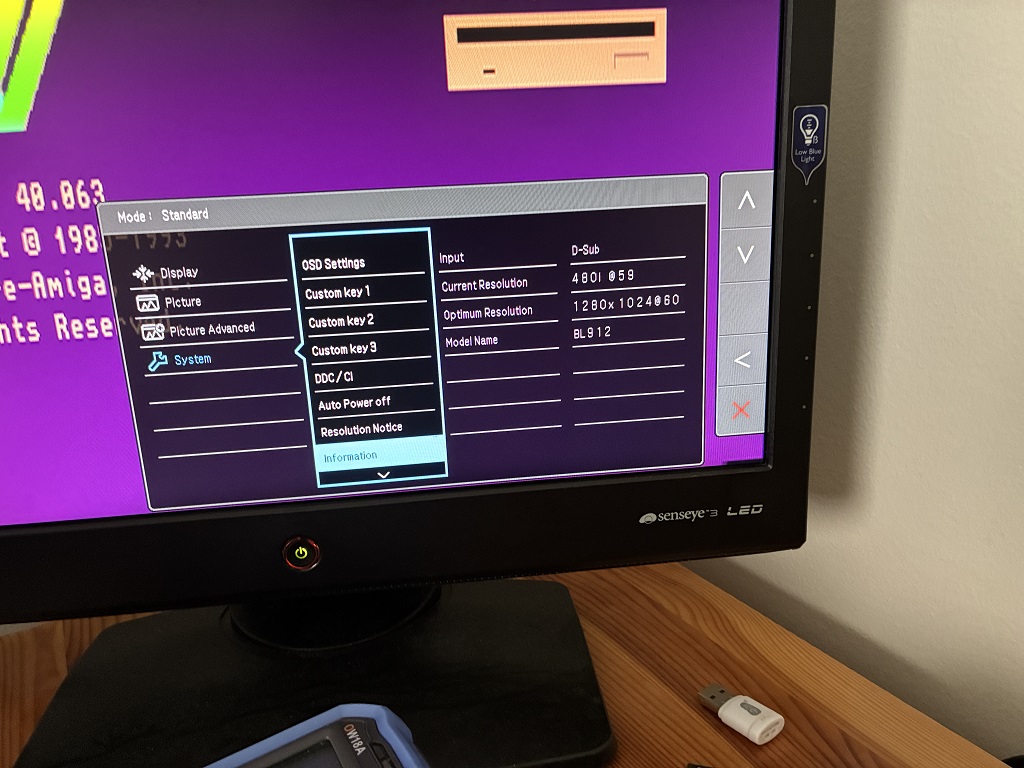
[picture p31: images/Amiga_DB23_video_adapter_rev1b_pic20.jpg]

</a>
<a href="images/Amiga_DB23_video_adapter_rev1b_pic21.jpg">
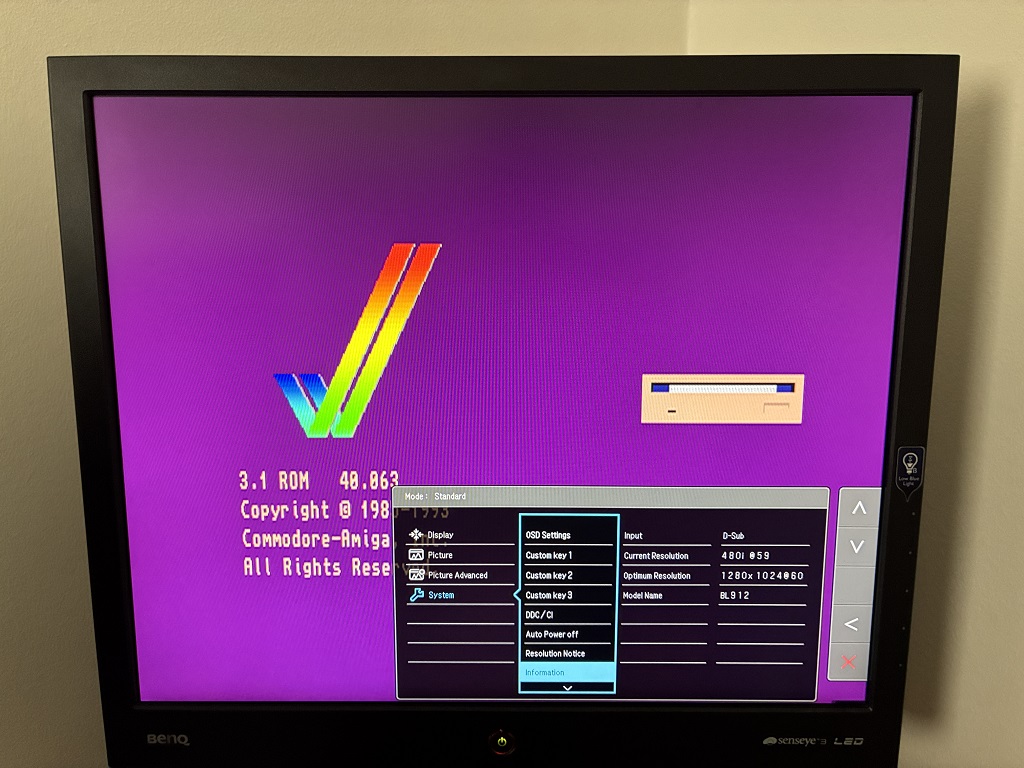
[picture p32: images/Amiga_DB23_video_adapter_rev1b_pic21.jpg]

</a>

**NTSC mode** — after flipping the switch on the adapter, the monitor information screen 
now shows 480i @ 59 Hz. The Kickstart 3.1 screen fills the display correctly with the 
proper NTSC aspect ratio.

### Working on the AOC 24E1Q — PAL and NTSC

<a href="images/Amiga_DB23_video_adapter_rev1b_pic24.jpg">
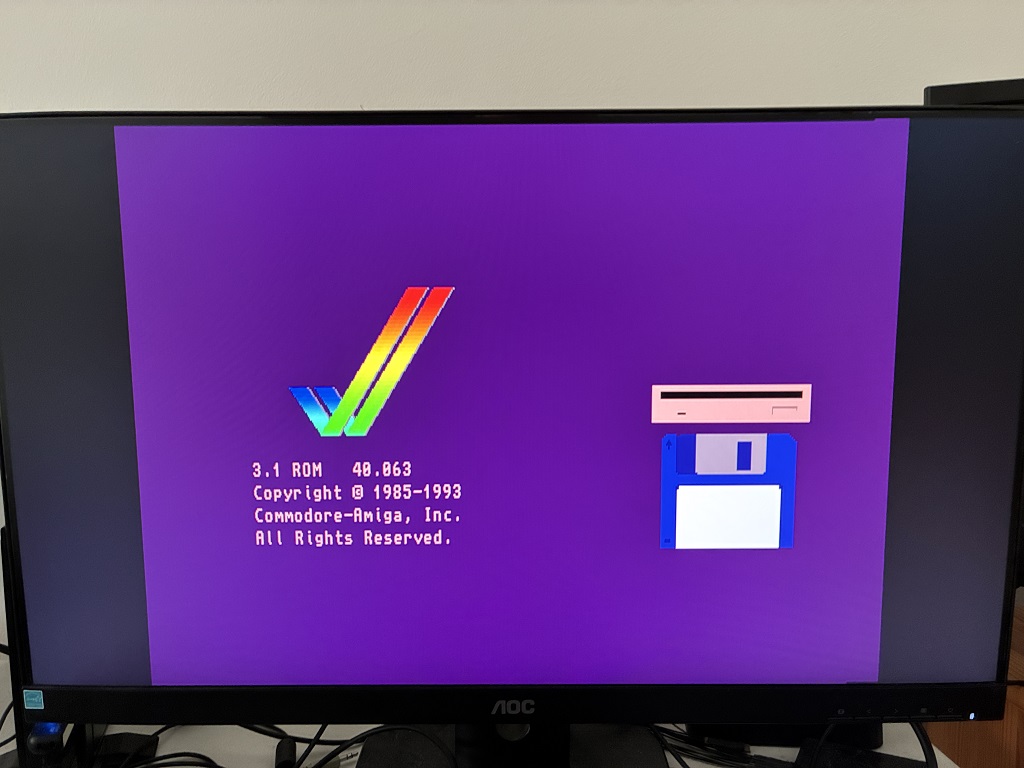
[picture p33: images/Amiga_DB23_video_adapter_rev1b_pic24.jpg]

</a>

**PAL mode** on the AOC 24E1Q displayed in 4:3 mode.

<a href="images/Amiga_DB23_video_adapter_rev1b_pic23.jpg">
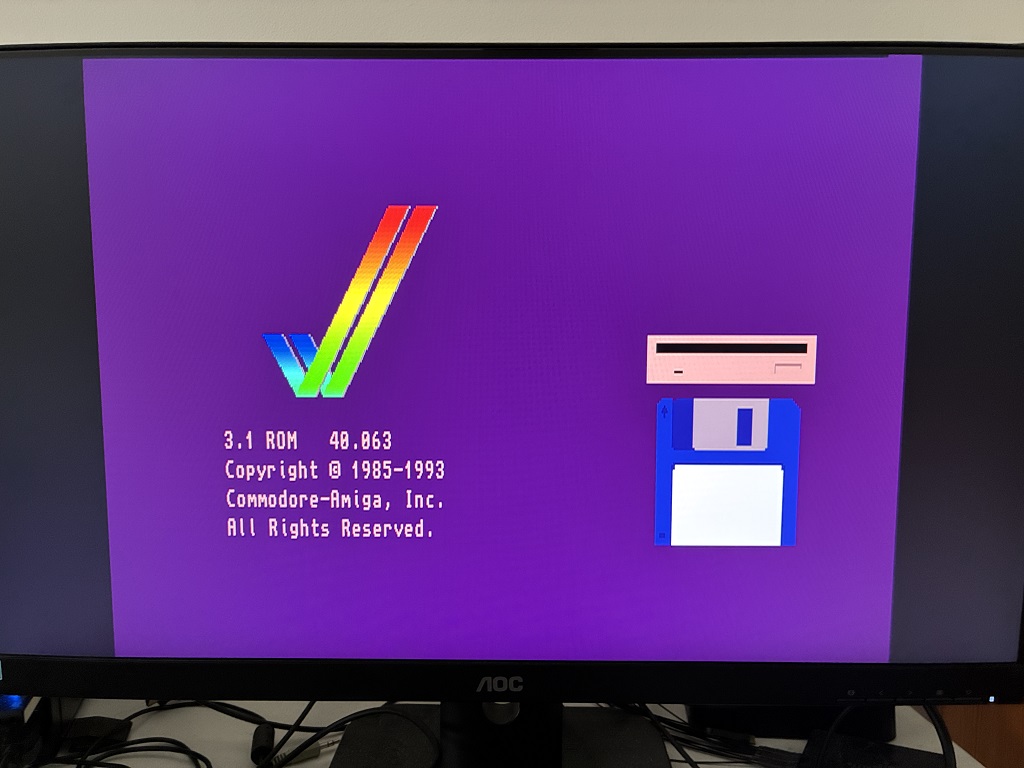
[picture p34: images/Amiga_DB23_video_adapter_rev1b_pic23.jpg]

</a>

**NTSC mode** on the AOC 24E1Q displayed in 4:3 mode.

### SCART cable on a Panasonic Plasma — PAL and NTSC

The SCART cable tested on a Panasonic plasma TV with the Amiga 500. The picture quality 
is outstanding — sharp, clean RGB with no banding or jailbar artefacts, almost HDMI-like 
in quality.

<a href="images/Amiga_DB23_video_adapter_rev1b_pic33.jpg">
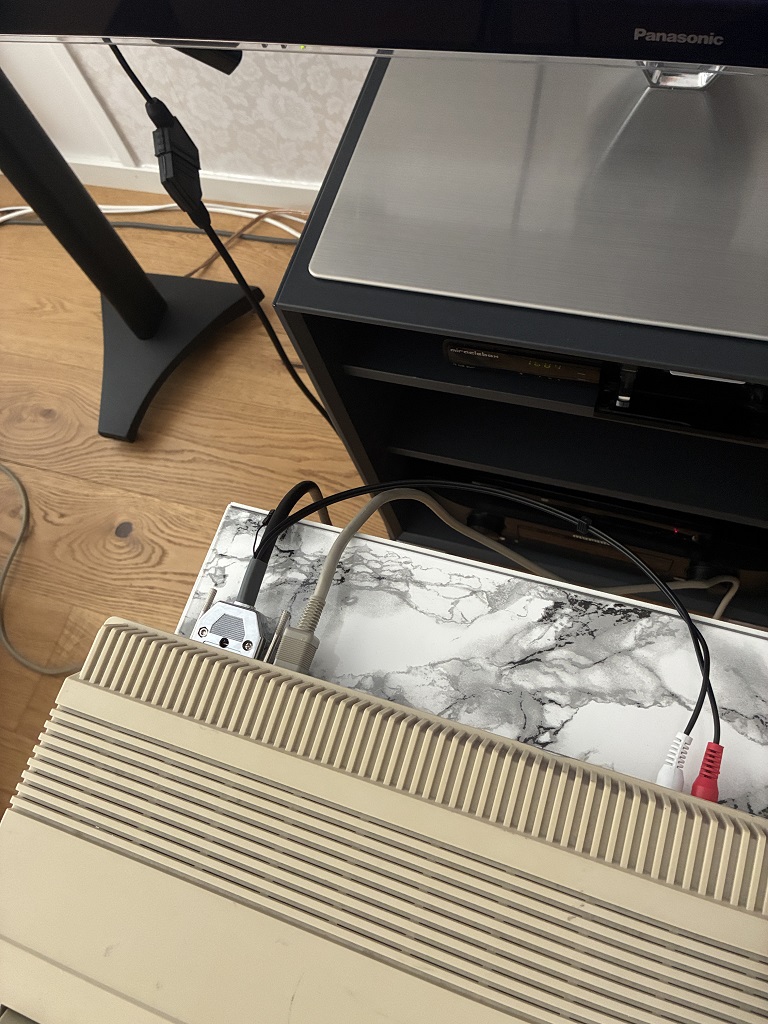
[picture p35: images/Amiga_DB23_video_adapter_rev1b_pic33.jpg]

</a>

The SCART cable running from the Amiga 500 to the Panasonic plasma, with the separate 
RCA audio cable also connected.

<a href="images/Amiga_DB23_video_adapter_rev1b_pic34.jpg">
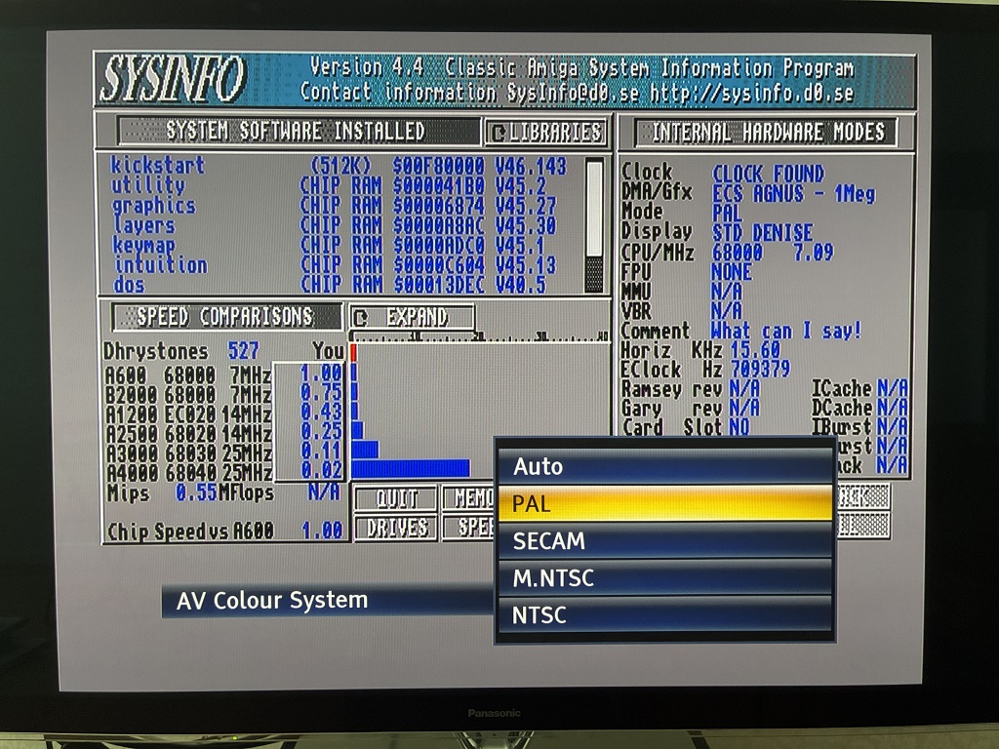
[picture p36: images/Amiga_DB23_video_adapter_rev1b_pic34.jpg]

</a>

**PAL mode** — SysInfo running on the Panasonic plasma via SCART. The TV OSD confirms 
the AV colour system. The Amiga is running from the internal 28.37516 MHz PAL oscillator 
on the motherboard, which is why the CPU speed is displayed as 7.09 MHz.

<a href="images/Amiga_DB23_video_adapter_rev1b_pic35.jpg">
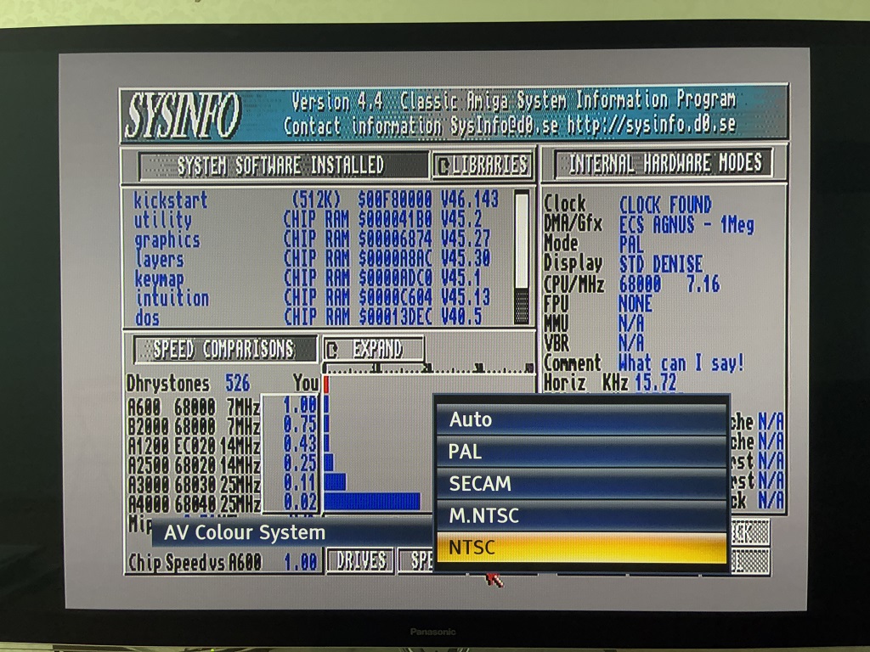
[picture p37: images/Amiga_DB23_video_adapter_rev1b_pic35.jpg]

</a>

**NTSC mode** — SysInfo after flipping the switch to engage the external XCLK 28.63636 
MHz oscillator circuit on the adapter. The CPU speed now reads 7.16 MHz confirming the 
machine is running on the NTSC clock. Both PAL and NTSC modes produce an excellent sharp 
picture via SCART.

<a href="images/Amiga_DB23_video_adapter_rev1b_pic36.jpg">
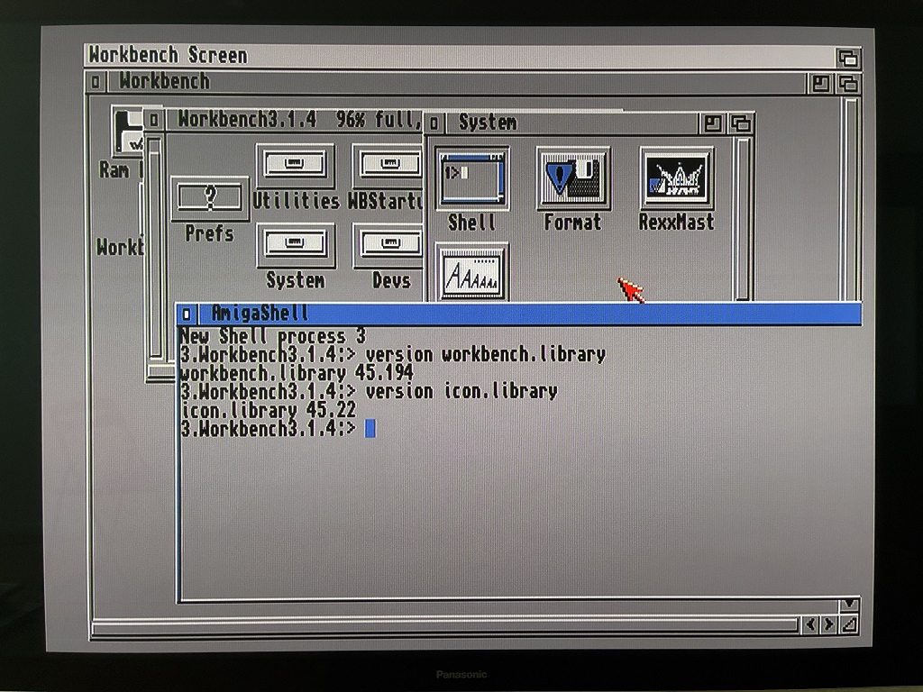
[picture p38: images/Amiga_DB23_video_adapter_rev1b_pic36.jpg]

</a>

Workbench 3.1.4 running in PAL mode on the Panasonic plasma via SCART. The picture 
quality speaks for itself.

---

## Optional mod: A500 Rev 6A hardware PAL/NTSC switching without a fly-lead

If you have an Amiga 500 Rev 6A motherboard, there is a neat alternative to running a 
separate fly-lead wire from the `XCLKEN` pad on the adapter back to Agnus pin 41. Instead 
of a wire, a single **1kΩ 1206 resistor** can be bodged directly between the `JP5C` pad 
and `JP4` pad 1 on the motherboard, connecting `_XCLKEN` to the Agnus PAL/NTSC pin 
(pin 41) via the existing JP4 jumper area.

> ⚠️ This mod assumes you have already **cut the trace between JP4 pad 1 and pad 2** 
> (which bridges pin 41 to GND on a standard PAL machine). Verify this cut with a 
> multimeter before proceeding — pad 1 must have no continuity to GND. Also confirm that 
> your Agnus revision supports hardware PAL/NTSC switching before attempting this mod.

The schematic excerpt below shows where the resistor connects:

<a href="images/A500_rev6a_PAL_NTSC_mod_pic1.png">
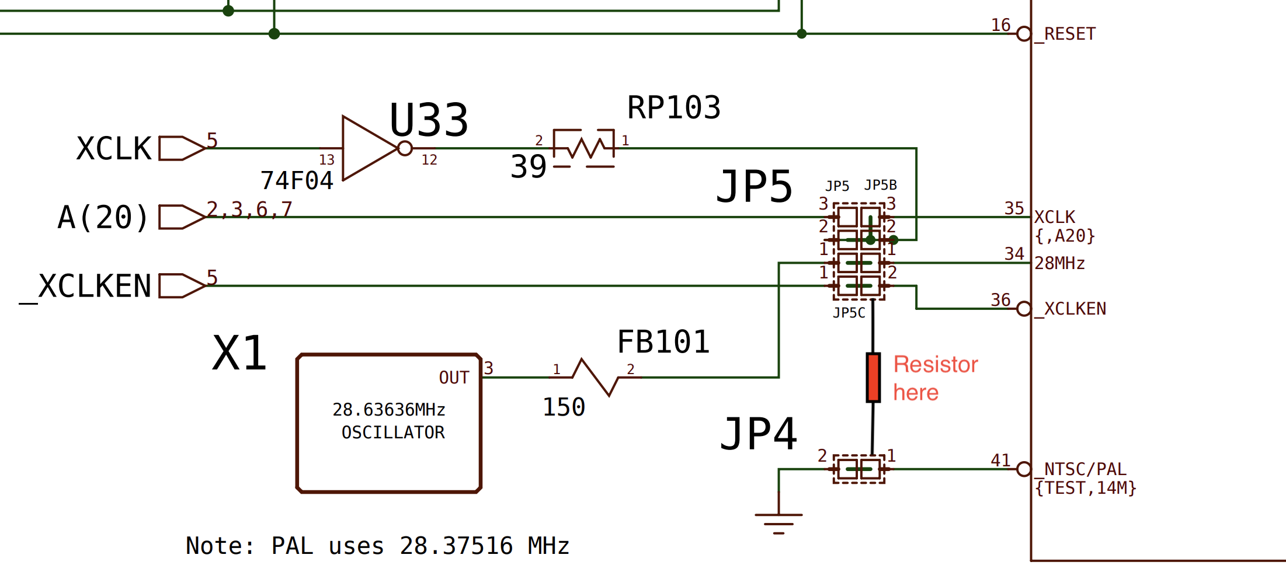
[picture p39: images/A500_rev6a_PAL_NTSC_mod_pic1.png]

</a>

The `_XCLKEN` signal (from JP5C) is connected through the 1kΩ resistor to JP4 pad 1, 
which leads to Agnus pin 41 (`_NTSC/PAL`). When the switch on the adapter asserts 
`_XCLKEN`, Agnus is simultaneously told to switch clock source, all controlled from the 
single switch on the DB23 plug — no separate fly-lead wire needed.

<a href="images/A500_rev6a_PAL_NTSC_mod_pic2.jpg">
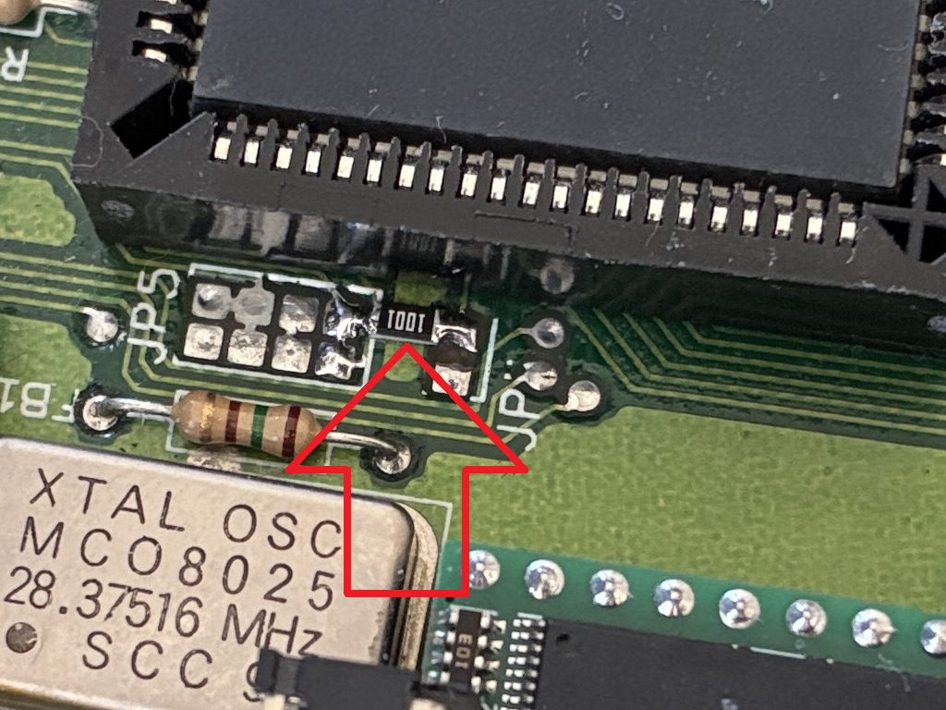
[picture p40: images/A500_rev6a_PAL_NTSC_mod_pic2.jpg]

</a>

A 1206 1kΩ resistor bodged between the JP5C and JP4 pad 1 on the A500 Rev 6A 
motherboard. The 1206 package is convenient here as its footprint spans the gap between 
the two pads neatly.

---

***
***
***

### OLD rev 1A:
***

<a href="images/Amiga_DB23_video_adapter_rev1a_pic1.png">

</a>
<a href="images/Amiga_DB23_video_adapter_rev1a_pic2.png">

</a>
<br />
<a href="images/Amiga_DB23_video_adapter_rev1a_pic4.png">

</a>
<a href="images/Amiga_DB23_video_adapter_rev1a_pic3.png">

</a>

***

The HSync and VSync lines are buffered via a dual non-inverting Schmitt-trigger IC to reduce jitter and noise. The PAL/NTSC switch has a simple resistor-capacitor (RC) debounce circuit using the hysteresis in a dual-inverting Schmitt-trigger IC for proper debounce in hardware. This IC also controls the enabling (OE-pin) of the crystal oscillator as well as asserting the /XCLKEN line (pin 2). A solderpad with a jumper-pin exists for connecting a jumper-wire back to a switchable Agnus (Not all Agnuses are switchable) on pin 41 (or JP4 on A500 Rev. 6A), this is completely optional, check your Agnus version before trying such a mod and that JP4 isn't bridged to GND. All ECS Agnuses can be switched in Software should your Agnus not have the PAL/NTSC pin. KS 3.0 and above lets you switch in early startup menu that you can access by holding down the two mouse buttons right after resetting the machine.

***

<a href="images/Amiga_DB23_video_adapter_rev1a_pic5.jpg">

</a>
<a href="images/Amiga_DB23_video_adapter_rev1a_pic6.jpg">

</a>
<a href="images/Amiga_DB23_video_adapter_rev1a_pic11.jpg">

</a>

***

With this adapter you can:

    1. Make an Amiga DB23 to SCART RGBS (RGB with CSync) cable, 
       and optionally populate X1 with either a 28.63636 MHz (NTSC) 
       or 28.37516 MHz (PAL) oscillator, obviously you'll choose a crystal here 
       opposite to what your machine has on the motherboard.

    or

    2. Make an Amiga DB23 to VGA RGBHV (RGB with separate HSync, VSync) cable 
       (This requires a 15 kHz compatible monitor http://15khz.wikidot.com/ ), 
       and optionally populate X1 with either a 28.63636 MHz (NTSC) 
       or 28.37516 MHz (PAL) oscillator, obviously you'll choose a crystal here 
       opposite to what your machine has on the motherboard.

    or

    3. Make a Plug-only with no cable and populate X1 with either a 28.63636 MHz (NTSC) 
       or 28.37516 MHz (PAL) oscillator, obviously you'll choose a crystal here 
       opposite to what your machine has on the motherboard. I assume you're using RGB2HDMI 
       or similar for hooking up your display but still want to be able to switch between true 
       PAL/NTSC by feeding XCLK to the machine.

***

If you use jumper-wire from JP1-pin then you bridge it either with the left pad or the right pad depending on your setup:

    1. Motherboard has PAL oscillator and Adapter has NTSC oscillator = bridge JP1-pin with XCLKEN-pad
    2. Motherboard has NTSC oscillator and Adapter has PAL oscillator = bridge JP1-pin with OE-pad

Please note, using a jumper-wire is completely optional, You can switch ECS Agnus in Early Startup menu or with software such as Degrader and then ju only switch the external XLCK-crystal enable or disable via the switch on the cable plug. However it can be more convenient to have both tasks controlled from one single switch, hence connecting a jumper-wire.

***

BOM SCART
---------
PART  | Value   | Description
----- | ------- | -------
R1    | 330 Ohm | 0805 &nbsp;&nbsp;&nbsp;(CSync), to Pin 20 of SCART, (Comp Video In, 1V including sync)
R2    | 75 Ohm  | 1206 &nbsp;&nbsp;&nbsp;(+5V), to Pin 16 of SCART, High (1-3V) RGB, Low (0-0.4V) Composite
R3    | 1k Ohm  | 1206 &nbsp;&nbsp;&nbsp;(+12V), to Pin 8 of SCART, Autoselect switch: High (9.5-12V) AVmode, Low (0-2V) TVmode

I used the Resistor-values following Stedy's guide here: <br /><br />
The Ultimate SCART cable <br />
http://ianstedman.co.uk/amiga-scart-guide/

BOM VGA
-------
PART  | Value     | Description
----- | --------- | -------
U1    | 74HCT2G17 | TSOP-6 (Dual non-inverting Schmitt trigger), (HSync, VSync) <br />https://assets.nexperia.com/documents/data-sheet/74HC_HCT2G17.pdf
C2    | 0.1 uF    | 0805

BOM XCLK
--------
PART  | Value      | Description
--------- | ---------- | -------
R4        | 10k Ohm    | 0805
R5        | 10k Ohm    | 0805
C1        | 0.1 uF     | 0805
C3        | 0.1 uF     | 0805
C4        | 0.1 uF     | 0805
U2        | 74HCT2G14  | TSOP-6 (Dual inverting Schmitt trigger) <br />https://assets.nexperia.com/documents/data-sheet/74HC_HCT2G14.pdf
X1 (PAL)  | 28.375 MHz  | Standard Clock Oscillator 5V (7.5 mm x 5 mm)<br />LFSPXO014117Bulk<br />https://eu.mouser.com/datasheet/2/741/LFSPXO014117Bulk-983232.pdf <br /> 91 pcs In Stock at the time of writing
X1 (NTSC) | 28.6363 MHz | XO (Standard) CMOS Oscillator 5V (7 mm x 5 mm)<br />K50-HC0CSE28.6363MR<br />https://media.digikey.com/pdf/Data%20Sheets/AVX%20PDFs/K50-HC%20Series%20Oscillators.pdf<br />895 pcs In Stock at the time of writing
JP1       | | Solder Jumper with pin for a flylead back to switchable Agnus pin 41 (or its pad on motherboard, e.g. JP4 on A500 Rev.6A)
SW1       | Handle length: 3mm-6mm| On-Off mini slide switch SS12D00 3pin 1P2T 2 Position toggle switch

***

## Howto modify a vga-cable and use with this adapter

First do some soldering, standard stuff nothing special:

<a href="images/Amiga_DB23_video_adapter_rev1a_pic7.jpg">

</a>
<a href="images/Amiga_DB23_video_adapter_rev1a_pic8.jpg">

</a>
<a href="images/Amiga_DB23_video_adapter_rev1a_pic9.jpg">

</a>

***

Ok good, now the switch, solder it on and make a hole in the plastic hood (several small drill holes will do, or one 5 mm bulls-eye drill hole.):
<br />

<a href="images/Amiga_DB23_video_adapter_rev1a_pic10.jpg">

</a>
<a href="images/Amiga_DB23_video_adapter_rev1a_pic11.jpg">

</a>
<a href="images/Amiga_DB23_video_adapter_rev1a_pic12.jpg">

</a>

***

Now time to butcher one side of the vga cable:

<br />
<a href="images/Amiga_DB23_video_adapter_rev1a_pic13.jpg">

</a>
<a href="images/Amiga_DB23_video_adapter_rev1a_pic14.jpg">

</a>
<a href="images/Amiga_DB23_video_adapter_rev1a_pic15.jpg">

</a>
<br />
<a href="images/Amiga_DB23_video_adapter_rev1a_pic16.jpg">

</a>
<a href="images/Amiga_DB23_video_adapter_rev1a_pic17.jpg">

</a>

***

Now, first thing first, put a larger shrink tube around the cable (blue in picture) and then start cutting and stripping wires, you can beep out which one is which. In this cable all the individually shielded wires were RGBHV. Wire together the cable shielding like in picture below and use a shrink tube around. Pic below says it all:

<a href="images/Amiga_DB23_video_adapter_rev1a_pic18.jpg">

</a>

***
Optional flylead:
<br /><br />
Now add a jumper wire with a right angled pin (crimped or soldered to the wire) and solder it onto JP1 bridging it with either of the pads (which one depends on your setup).

<a href="images/Amiga_DB23_video_adapter_rev1a_pic19.jpg">

</a>
<a href="images/Amiga_DB23_video_adapter_rev1a_pic20.jpg">

</a>

***
Now, solder the shielding to the metal casing, I first tried without crimping a pin on there but couldn't get a good joint. I used my desolder gun 80W giving enough juice/heat to be able to solder this one finally:

<a href="images/Amiga_DB23_video_adapter_rev1a_pic21.jpg">

</a>
<br />

Ok, now heat the blue shrink tube and fit the cable stop, don't tighten too hard.

<a href="images/Amiga_DB23_video_adapter_rev1a_pic22.jpg">

</a>

<br />

I did some testing that the switch works, and also I beeped out the cable verifying no shorts exists before trying it:

<a href="images/Amiga_DB23_video_adapter_rev1a_pic23.jpg">

</a>
<a href="images/Amiga_DB23_video_adapter_rev1a_pic24.jpg">

</a>

***
Installing jumper wire in A500 Rev 6A:
<br />

I ran the jumper wire through an existing hole in the Amiga 500 case/motherboard, then just soldered it onto JP4 pad next to Agnus verifying no continuity to GND-pad:

<a href="images/Amiga_DB23_video_adapter_rev1a_pic25.jpg">

</a>
<a href="images/Amiga_DB23_video_adapter_rev1a_pic26.jpg">

</a>

***

All done! We can now switch between true PAL/NTSC and get correct display resolution, yay!

<a href="images/Amiga_DB23_video_adapter_rev1a_pic27.jpg">

</a>
<a href="images/Amiga_DB23_video_adapter_rev1a_pic28.jpg">

</a>

***

We can even switch during run-time thanks to the proper debounce circuit in hardware, but I think it's best to power off the Amiga, do the switching, and then power on again.

Short video-clip below showing hot-switching, don't try this at home folks ;)

https://imgur.com/iBLLAlT

Here a comparison between PAL vs NTSC on WB 3.1.4 on a A1200 and a Benq BL912 tweaked with pixelclock setting around 90 and some overscan, very nice picture quality I must say:

<a href="images/Amiga_DB23_video_adapter_rev1a_pic29.jpg">

</a>
<a href="images/Amiga_DB23_video_adapter_rev1a_pic30.jpg">

</a>
<br />
<br />
It is very important to adjust the pixelclock on the Benq monitor to get rid of those vertical jailbars, otherwise it will look like this:
<br />
<br />
<a href="images/Amiga_DB23_video_adapter_rev1a_pic31.jpg">

</a>
<br />
<br />
If you ever wondered how one of those moulded vga plugs looks like inside, this is it:
<br />
<br />
<a href="images/Amiga_DB23_video_adapter_rev1a_pic32.jpg">

</a>

***

## Howto solder a SCART-cable (RGBS) with this adapter.

<br />
<a href="images/Amiga_DB23_video_adapter_rev1a_pic33.jpg">

</a>
<br />
<br />
First the resistors R1-R3 and then the oscillator with its decoupling cap:
<br />
<br />
<a href="images/Amiga_DB23_video_adapter_rev1a_pic34.jpg">

</a>
<a href="images/Amiga_DB23_video_adapter_rev1a_pic35.jpg">

</a>
<a href="images/Amiga_DB23_video_adapter_rev1a_pic36.jpg">

</a>

***

I'm using a cut-down DB25 to DB23 here and because of this I didn't solder the PCB flush against the connector as you would normally do, this is to make the PCB fit in the slighly larger plastic shroud of the DB25. Solder the mini-slide switch as the last step after the 23-pins for easier soldering:

<a href="images/Amiga_DB23_video_adapter_rev1a_pic37.jpg">

</a>
<a href="images/Amiga_DB23_video_adapter_rev1a_pic38.jpg">

</a>
<a href="images/Amiga_DB23_video_adapter_rev1a_pic39.jpg">

</a>

<br />
<br />

Drill out a hole for the switch 5 mm or similar and if needed cut some plastic from the shroud to clear the oscillator:

<br />
<a href="images/Amiga_DB23_video_adapter_rev1a_pic37.jpg">

</a>
<a href="images/Amiga_DB23_video_adapter_rev1a_pic38.jpg">

</a>
<a href="images/Amiga_DB23_video_adapter_rev1a_pic39.jpg">

</a>
<br />
<a href="images/Amiga_DB23_video_adapter_rev1a_pic40.jpg">

</a>
<a href="images/Amiga_DB23_video_adapter_rev1a_pic41.jpg">

</a>
<a href="images/Amiga_DB23_video_adapter_rev1a_pic42.jpg">

</a>
<br />
<a href="images/Amiga_DB23_video_adapter_rev1a_pic43.jpg">

</a>
<a href="images/Amiga_DB23_video_adapter_rev1a_pic44.jpg">

</a>

***

Now, add shrinktubes on the main cable and for the shielding and the L and R audio wires...then solder all the wires to the PCB and crimp the audio wires together, audio GND can be wired together and soldered to the GND pad(s) of the PCB:
<br />
<br />
<a href="images/Amiga_DB23_video_adapter_rev1a_pic45.jpg">

</a>
<a href="images/Amiga_DB23_video_adapter_rev1a_pic46.jpg">

</a>
<br />
<br />
Add the jumper-wire-pin and solder the slide switch and the shielding last (I use my desolder gun 80W to be able to solder the shielding):
<br />
<br />
<a href="images/Amiga_DB23_video_adapter_rev1a_pic47.jpg">

</a>
<a href="images/Amiga_DB23_video_adapter_rev1a_pic48.jpg">

</a>
<a href="images/Amiga_DB23_video_adapter_rev1a_pic49.jpg">

</a>
<br />
<br />
Ok all done with the d-sub connector...
<br />
<br />
<a href="images/Amiga_DB23_video_adapter_rev1a_pic50.jpg">

</a>
<br />
<br />
...now the Scart-plug, this is straight forward soldering, nothing special, I use a stick from a q-tip to separate the pin rows to not risk any shorts. I find it holds the pins better in position too.
<br />
<br />
<a href="images/Amiga_DB23_video_adapter_rev1a_pic51.jpg">

</a>
<a href="images/Amiga_DB23_video_adapter_rev1a_pic52.jpg">

</a>
<a href="images/Amiga_DB23_video_adapter_rev1a_pic53.jpg">

</a>

***

<a href="images/Amiga_DB23_video_adapter_rev1a_pic54.jpg">

</a>
<br />
All done!
<br />
<br />
Here another SCART-cable I made, this time with a real DB23 plug:
<br />
<br />
<a href="images/Amiga_DB23_video_adapter_rev1a_pic55.jpg">

</a>
<a href="images/Amiga_DB23_video_adapter_rev1a_pic56.jpg">

</a>

***
As a last step, don't forget to select Game Mode and the correct AV-mode on your TV.
<br />
<br />
<a href="images/Amiga_DB23_video_adapter_rev1a_pic57.jpg">

</a>
<a href="images/Amiga_DB23_video_adapter_rev1a_pic58.jpg">

</a>
<br />
<br />
Game On!
<br />
<br />
Happy Hackin´

***

<br />
<br />

[][cc-by-sa]

This work is licensed under a
[Creative Commons Attribution-ShareAlike 4.0 International License][cc-by-sa].

[][cc-by-sa]

[cc-by-sa]: http://creativecommons.org/licenses/by-sa/4.0/
[cc-by-sa-image]: https://licensebuttons.net/l/by-sa/4.0/88x31.png
[cc-by-sa-shield]: https://img.shields.io/badge/License-CC%20BY--SA%204.0-lightgrey.svg

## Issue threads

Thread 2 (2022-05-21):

work for an a2000?

ogg1e, 2022-05-21:
I'm assuming this won't work in an a2000? I believe these need to be buffered to work in an a2000.

jbilander, 2022-05-21:
Hi,

It'll work will all Amigas, no problem. It is buffered with a 74HCT2G17 chip for V-Sync and H-Sync. Buffering is only when you make a VGA-cable with this PCB which in turn requires a 15 KHz compatible monitor. If you make a SCART-cable with this PCB which is also possible to do then you use C-Sync and no buffering is needed but rather you put a resistor to attenuate the signal.

Closed 2022-05-21.

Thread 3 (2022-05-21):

Can you use this just to buffer as well?

ogg1e, 2022-05-21:
What happens if you have this configured to be NTSC, and connect it to an NTSC amiga and monitor? Will it still work, or does it expect the machine and monitor to be opposite?

jbilander, 2022-05-21:
Populating the crystal oscillator and the switch and U2 on the PCB is completely optional and not needed in order to make a VGA or SCART-cable. Leave out everything on the BOM XCLK if you don't want this feature. It is a nice feature to make your machine dual native mode NTSC/PAL. It's there to make it possible to run the Amiga from this external Oscillator rather than the internal one. If you put a NTSC-oscillator (28.63636 MHz) on here and the internal Oscillator in the Amiga is also 28.63636 MHz you will only switch between two oscillator with the same frequency so it doesn't make sense to do this. It will work but I don't see the point in doing this unless the internal oscillator is broken or malfunctioning. What the switch does is switching between Enabling/Disabling the external Oscillator feed. If you have a NTSC-Amiga then you have a 28.63636 MHz internally, now if you put a 28.37516 MHz (PAL) on the PCB you can now select between PAL/NTSC with a flick of a switch. The setup could also be vice versa of course, you have 28.37516 MHz internally and 28.63636 MHz externally on the PCB.

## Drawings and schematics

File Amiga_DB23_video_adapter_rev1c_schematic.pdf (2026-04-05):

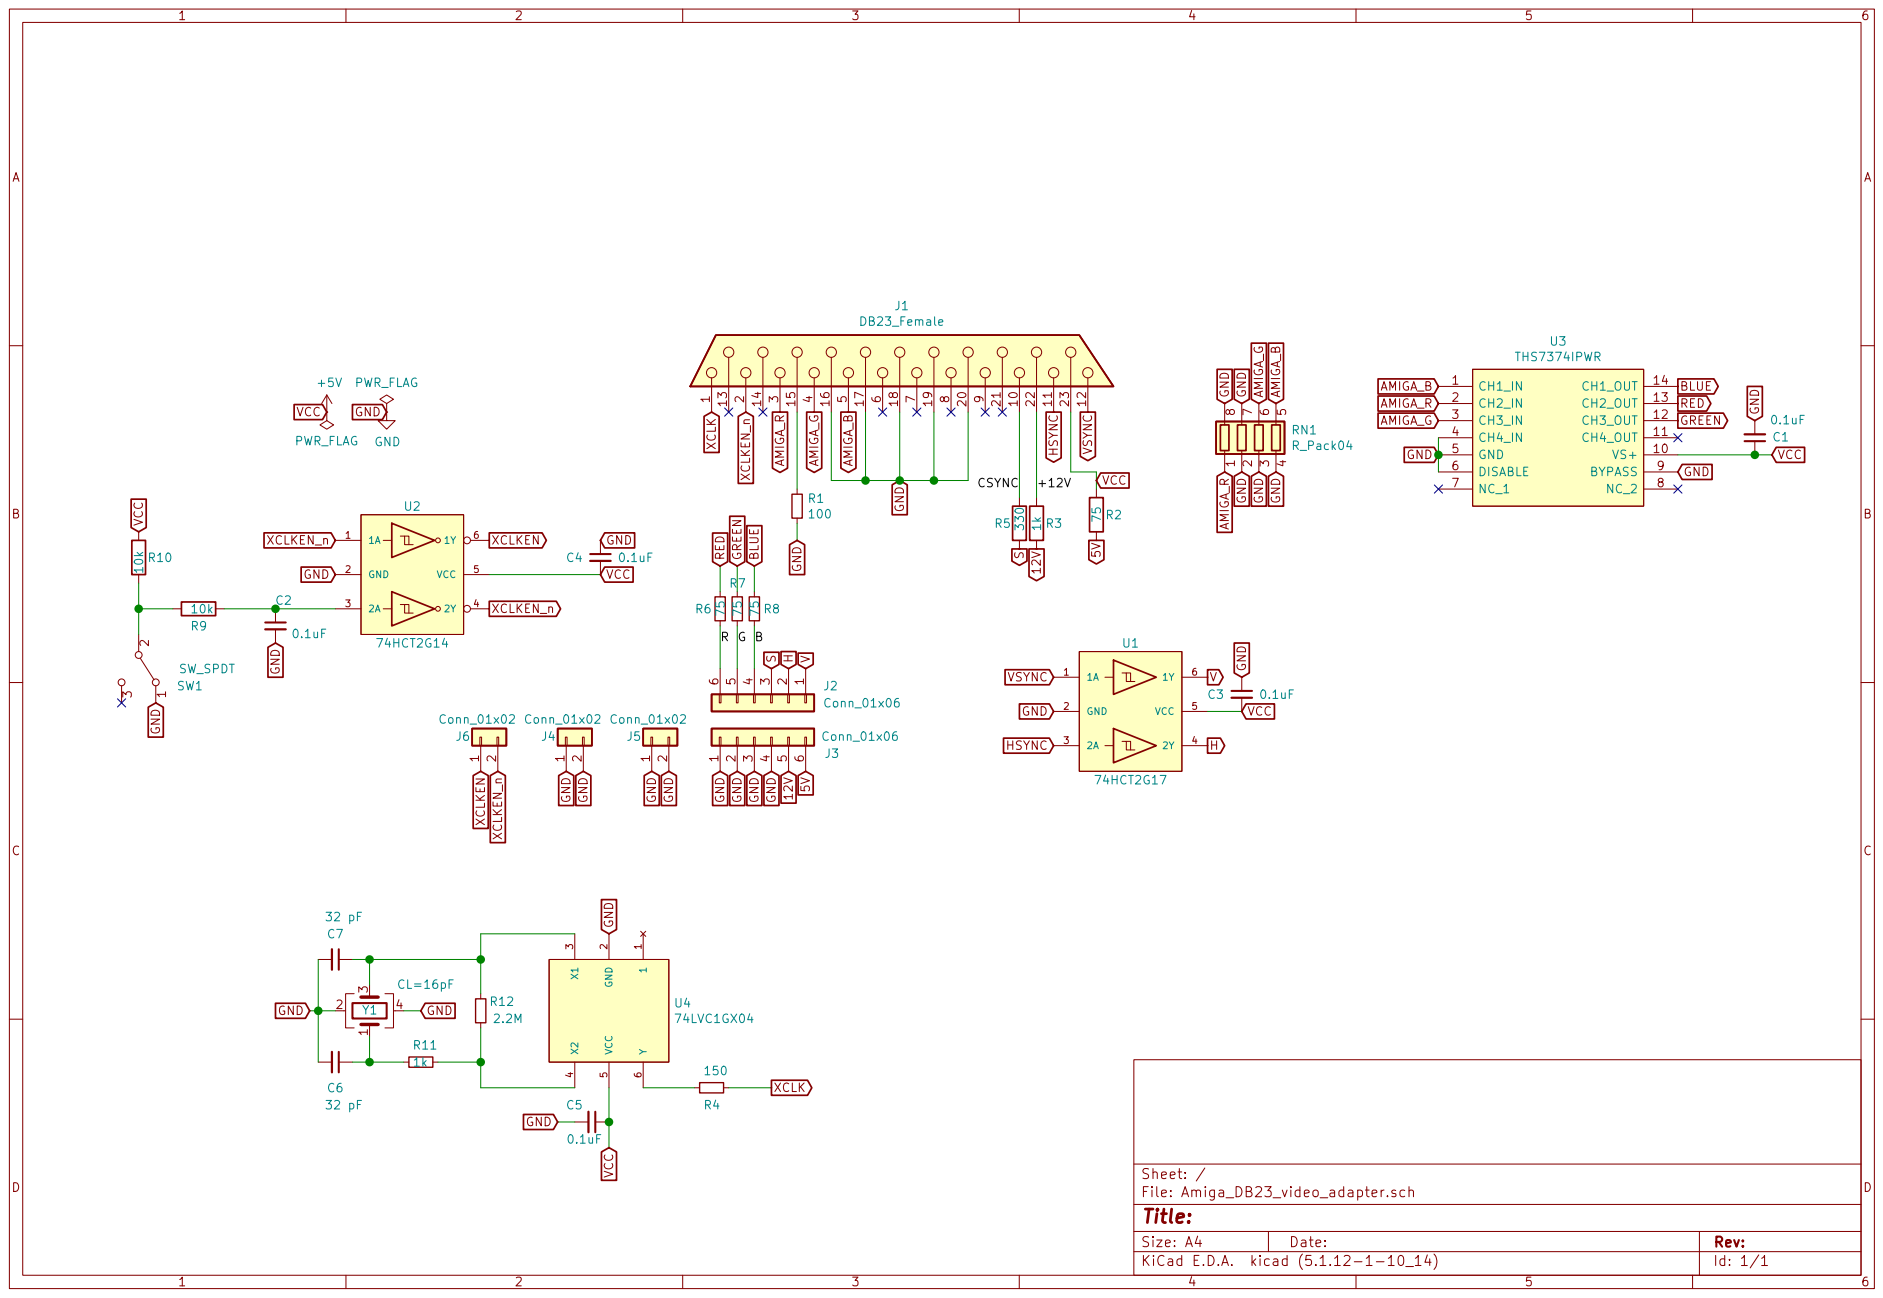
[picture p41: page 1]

S GND GND VCC GND GND GND

VSYNC GND GND GND GND

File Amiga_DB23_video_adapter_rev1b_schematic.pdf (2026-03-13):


S GND GND VCC GND GND GND

VSYNC GND GND GND GND

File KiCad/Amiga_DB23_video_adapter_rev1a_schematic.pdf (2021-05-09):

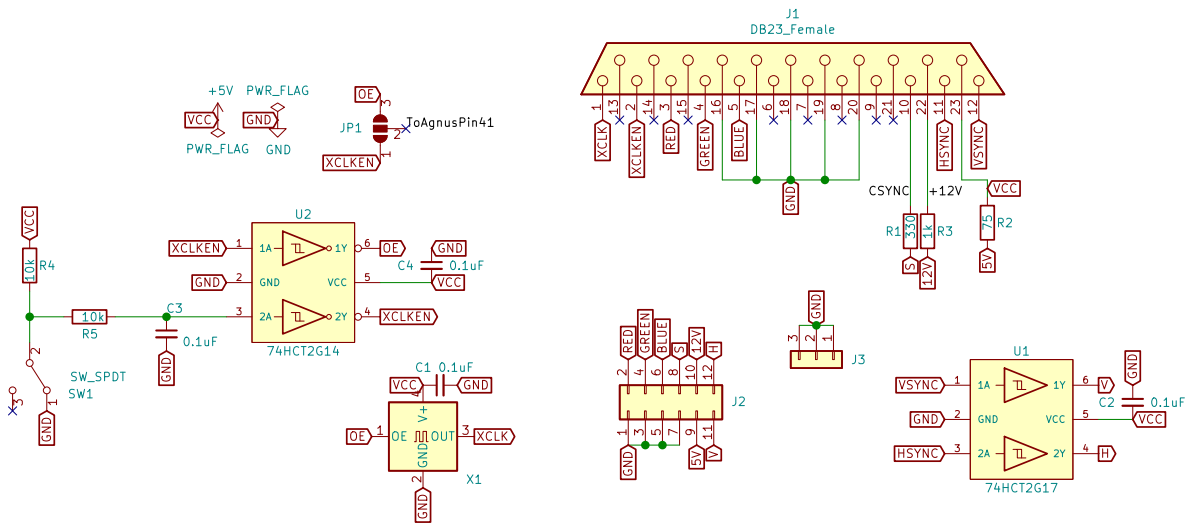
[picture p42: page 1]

S GND BLUE GND GREENXCLKEN OE OE GND VCC

H V GND GND GND 12V HSYNC 5V

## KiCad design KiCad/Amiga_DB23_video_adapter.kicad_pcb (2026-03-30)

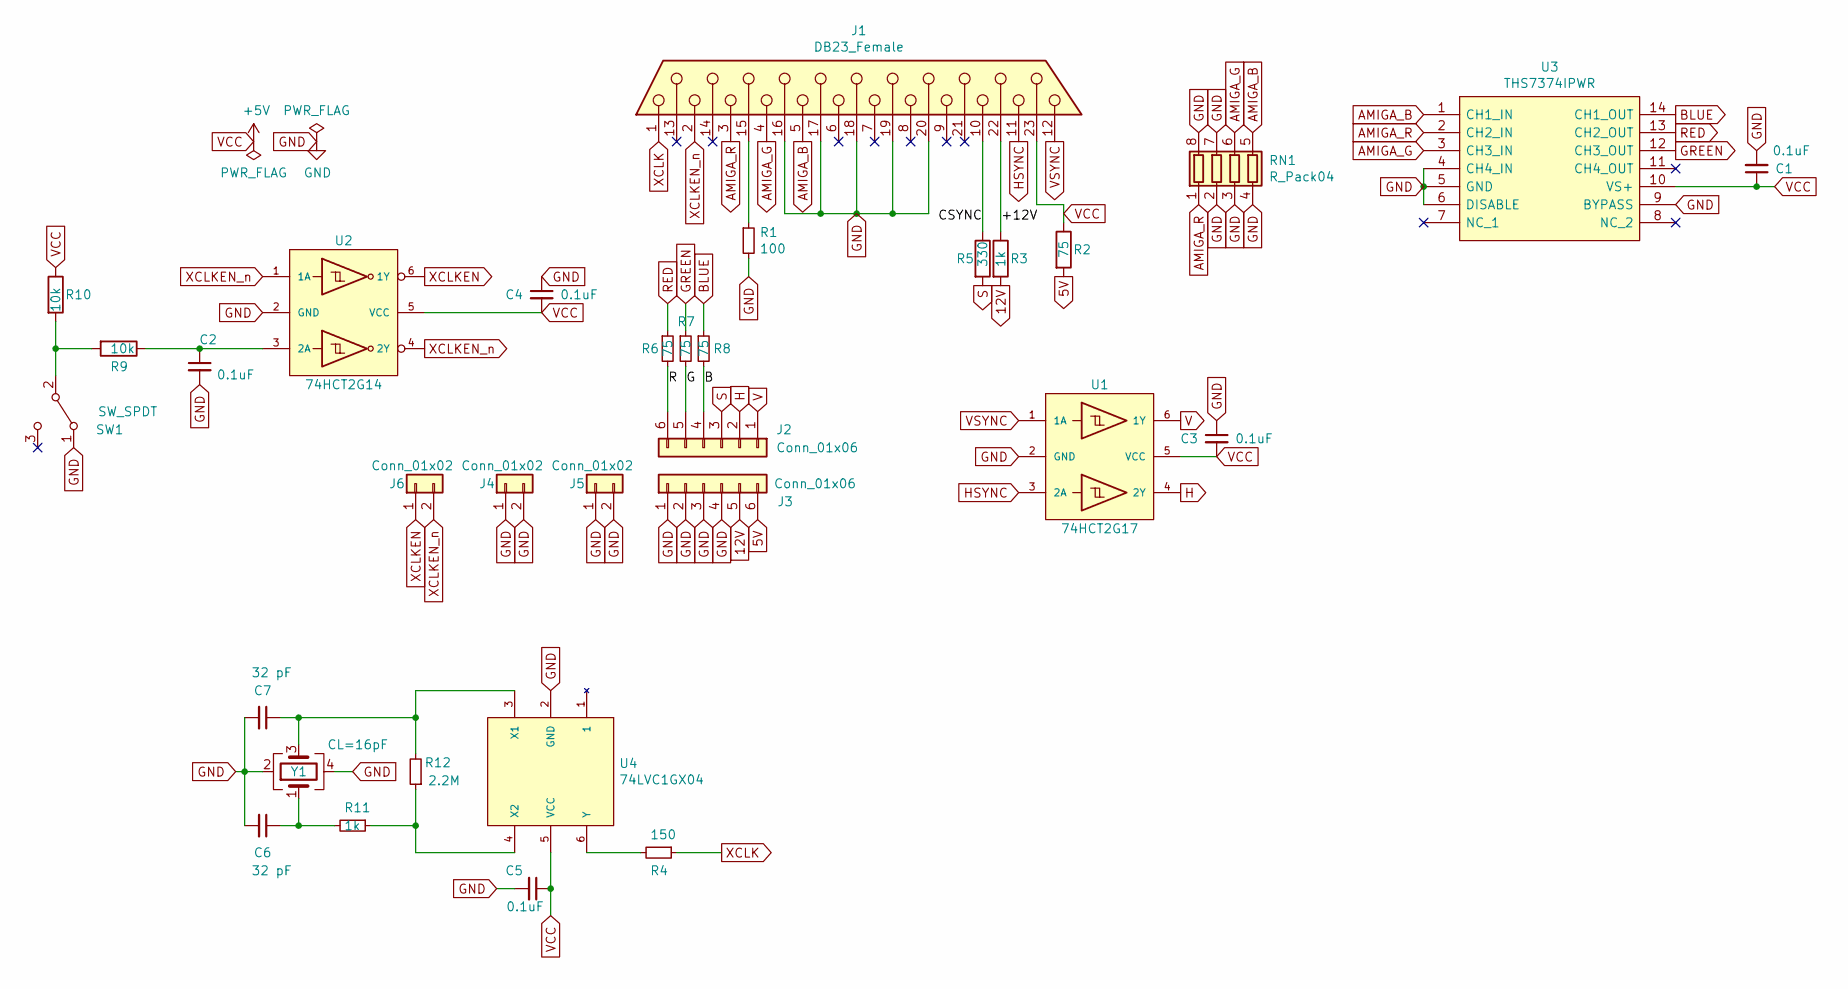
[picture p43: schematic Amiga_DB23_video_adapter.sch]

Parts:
C1, C2: 0.1uF; C_0805_2012Metric_Pad1.15x1.40mm_HandSolder
C3, C4, C5: 0.1uF; C_0603_1608Metric_Pad1.08x0.95mm_HandSolder
C6, C7: 32 pF; C_0603_1608Metric_Pad1.08x0.95mm_HandSolder
J1: DB23_Female; DSUB-23_Female_EdgeMount_P2.77mm
J2, J3: Conn_01x06; PinHeader_1x06_P2.00mm_Vertical
J4, J5, J6: Conn_01x02; PinHeader_1x02_P2.00mm_Vertical
R1: 100; R_1206_3216Metric_Pad1.30x1.75mm_HandSolder
R2: 75; R_1206_3216Metric_Pad1.42x1.75mm_HandSolder
R3: 1k; R_1206_3216Metric_Pad1.42x1.75mm_HandSolder
R4: 150; R_1206_3216Metric_Pad1.30x1.75mm_HandSolder
R5: 330; R_0805_2012Metric_Pad1.15x1.40mm_HandSolder
R6, R7, R8: 75; R_0603_1608Metric_Pad0.98x0.95mm_HandSolder
R9, R10: 10k; R_0805_2012Metric_Pad1.15x1.40mm_HandSolder
R11: 1k; R_0603_1608Metric_Pad0.98x0.95mm_HandSolder
R12: 2.2M; R_0603_1608Metric_Pad0.98x0.95mm_HandSolder
RN1: R_Pack04; RESCAF80P320X160X60-8N
SW1: SW_SPDT; PinHeader_1x03_P2.54mm_Vertical
U1: 74HCT2G17; TSOP-6_1.65x3.05mm_P0.95mm
U2: 74HCT2G14; TSOP-6_1.65x3.05mm_P0.95mm
U3: THS7374IPWR; TSSOP-14_4.4x5mm_P0.65mm
U4: 74LVC1GX04; TSOP-6_1.65x3.05mm_P0.95mm
Y1: CL=16pF; Crystal_SMD_SeikoEpson_FA238-4Pin_3.2x2.5mm

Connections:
5V: J3.6, R2.2
12V: J3.5, R3.2
/+12V: J1.22, R3.1
/B: J2.4, R8.2
/CSYNC: J1.10, R5.1
/G: J2.5, R7.2
/R: J2.6, R6.2
AMIGA_B: J1.5, RN1.5 (R4.2), U3.1 (CH1_IN)
AMIGA_G: J1.4, RN1.6 (R3.2), U3.3 (CH3_IN)
AMIGA_R: J1.3, RN1.1 (R1.1), U3.2 (CH2_IN)
BLUE: R8.1, U3.14 (CH1_OUT)
GND: C1.2, C2.2, C3.1, C4.1, C5.2, C6.2, C7.2, J1.16, J1.17, J1.18, J1.19, J1.20, J3.1, J3.2, J3.3, J3.4, J4.1, J4.2, J5.1, J5.2, R1.2, RN1.2 (R2.1), RN1.3 (R3.1), RN1.4 (R4.1), RN1.7 (R2.2), RN1.8 (R1.2), SW1.1 (A), U1.2 (GND), U2.2 (GND), U3.4 (CH4_IN), U3.5 (GND), U3.6 (DISABLE), U3.9 (BYPASS), U4.2 (GND), Y1.2, Y1.4
GREEN: R7.1, U3.12 (CH3_OUT)
H: J2.2, U1.4 (2Y)
HSYNC: J1.11, U1.3 (2A)
unnamed: C2.1, R9.1, U2.3 (2A)
unnamed: C6.1, R11.2, Y1.1
unnamed: C7.1, R12.2, U4.3 (X1), Y1.3
unnamed: J1.15, R1.1
unnamed: R4.2, U4.6 (Y)
unnamed: R9.2, R10.2, SW1.2 (B)
unnamed: R11.1, R12.1, U4.4 (X2)
RED: R6.1, U3.13 (CH2_OUT)
S: J2.3, R5.2
V: J2.1, U1.6 (1Y)
VCC: C1.1, C3.2, C4.2, C5.1, J1.23, R2.1, R10.1, U1.5 (VCC), U2.5 (VCC), U3.10 (VS+), U4.5 (VCC)
VSYNC: J1.12, U1.1 (1A)
XCLK: J1.1, R4.1
XCLKEN: J6.1, U2.6 (1Y)
XCLKEN_n: J1.2, J6.2, U2.1 (1A), U2.4 (2Y)

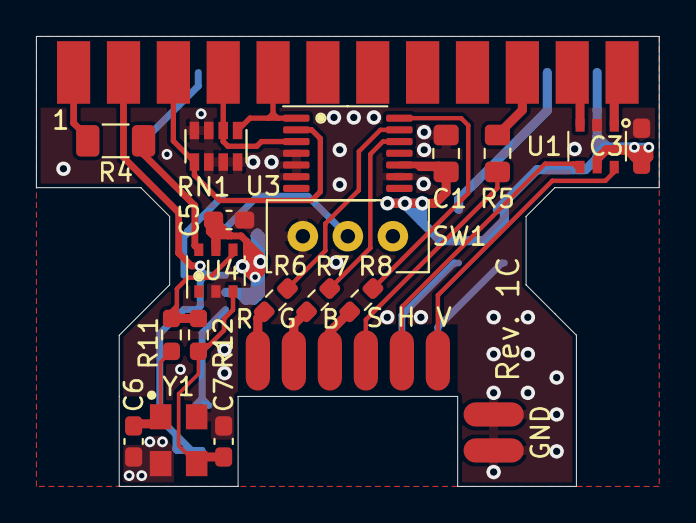
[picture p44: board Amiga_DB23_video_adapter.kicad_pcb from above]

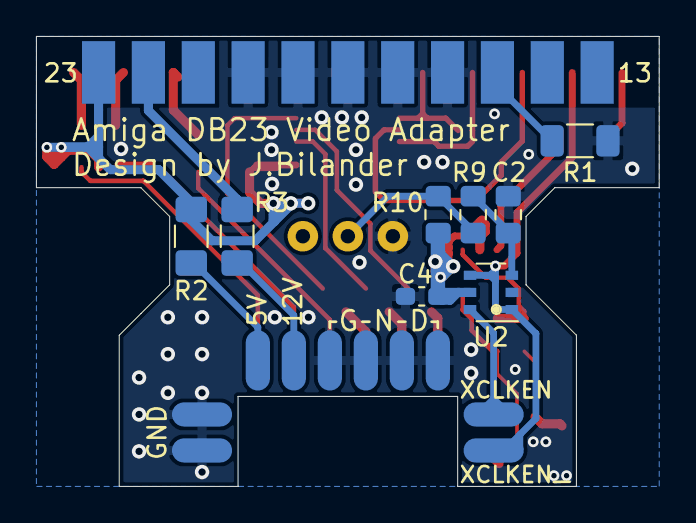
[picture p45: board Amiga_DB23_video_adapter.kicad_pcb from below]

Board: 4 copper layers, 34.6 x 25.0 mm, 32 parts (11 on the bottom side), 30 nets.

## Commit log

2026-03-08 Add footprint
2026-03-08 Add footprint folder
2026-03-12 Add new design based on a THS7374IPWR, 28M oscillator circuit, remove SolderJumper, complete re-design and re-route
    [Amiga_DB23_video_adapter.kicad_pcb, Amiga_DB23_video_adapter.sch]
2026-03-13 Add 3D model of resistor network
2026-03-13 Improve GND-stitching and fix silkscreen text and add new revision identifier
    [Amiga_DB23_video_adapter.kicad_pcb, Amiga_DB23_video_adapter.sch]
2026-03-13 Swap references C2,C3. Swap references C5,C7. Swap references R1,R9. Swap references R4,R12
    [Amiga_DB23_video_adapter.kicad_pcb, Amiga_DB23_video_adapter.sch]
2026-03-13 Swap references R5,R9. Swap references R10,R12
    [Amiga_DB23_video_adapter.kicad_pcb, Amiga_DB23_video_adapter.sch]
2026-03-13 Swap references R11,R12 and fix positioning of R10
    [Amiga_DB23_video_adapter.kicad_pcb, Amiga_DB23_video_adapter.sch]
2026-03-13 Update with new plot settings
    [Amiga_DB23_video_adapter.kicad_pcb]
2026-03-13 Add schematic pdf
2026-03-30 Small fix of physical size to better fit the plastic DB23 shell, bump to Rev 1C
    [Amiga_DB23_video_adapter.kicad_pcb]
2026-04-04 Update README.md
    docs: update README for Rev 1B with build guide.
    - Add step-by-step Rev 1B build guide with photos (pic5–pic16) covering connector preparation, PCB fitting, shell modification, strain relief, switch hole drilling and cable wiring
2026-04-05 docs: add Rev 1B in-action section with photos of cable connected to Amiga 500+
2026-05-08 docs: add SCART cable build guide with photos (pic25–pic32)
2026-05-09 docs: add Panasonic plasma SCART results and A500 Rev 6A resistor bodge mod

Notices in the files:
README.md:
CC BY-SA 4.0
